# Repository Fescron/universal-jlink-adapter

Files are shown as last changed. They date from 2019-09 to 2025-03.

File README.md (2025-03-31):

# Universal J-Link Adapter







<br/>

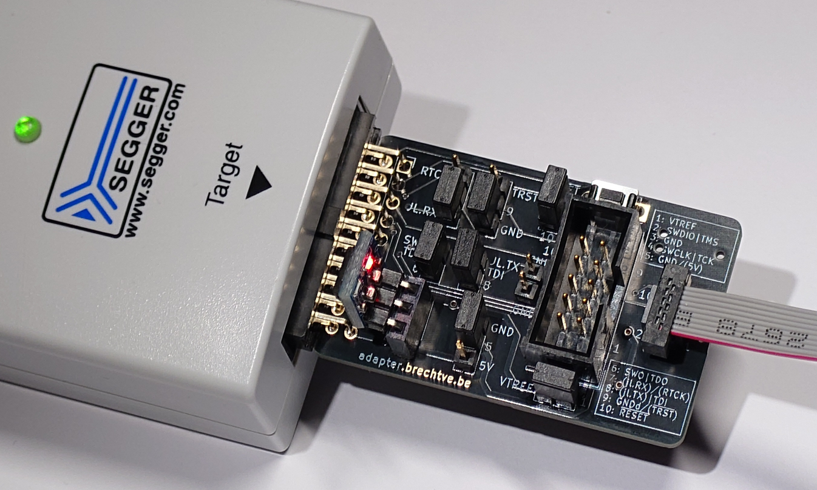
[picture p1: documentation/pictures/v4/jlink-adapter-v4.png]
Universal J-Link adapter on J-Link EDU debugger


<br/>

| Quick access links                                                                                                                                                                        |
| ----------------------------------------------------------------------------------------------------------------------------------------------------------------------------------------- |
| [Adapter v4.0 **schematic** (PDF)](hardware/jlink-tagConnect-adapter-v4/jlink-tagConnect-adapter-v4.pdf) // [Adapter v4.0 **gerber-files**](hardware/jlink-tagConnect-adapter-v4/Gerber/) |
| [Basic **J-Link Commander** usage and using **Segger Real-Time Transfer (RTT)** (instead of UART) for real-time debugging](JLinkExe-SeggerRTT-debugging-TipsTricks.md)                    |

<br/>

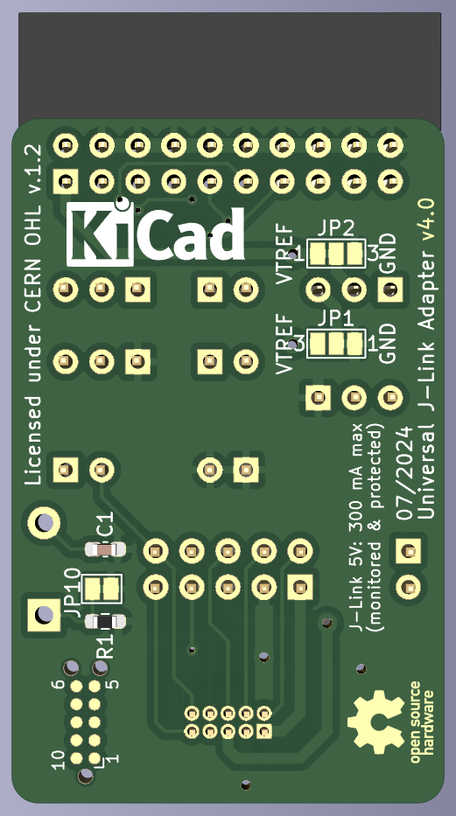
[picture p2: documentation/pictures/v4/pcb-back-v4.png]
Back of the adapter board


This multifunctional adapter board, primarily designed for use with a [J-Link debugger](https://www.segger.com/products/debug-probes/j-link/) (but others which follow the standard 20-pin JTAG/SWD pinout also work), allows the user to have the standard [9 pin Cortex-M SWD/JTAG pinout](https://www.segger.com/products/debug-probes/j-link/accessories/adapters/9-pin-cortex-m-adapter/) on both a 0.1" (2.54mm) and 0.05" (1.27mm) male pinheader. With additional jumpers it is possible to have **extra functionality** like **UART debugging though the J-Link's VCOM** on pins which normally aren't used in some modes, if the probe's hardware supports this. Good **labeling of all pin numbers and their corresponding functionality** also help to speed-up the embedded-development process. Additional information regarding the pinout of *default* SWD-headers as well as the voltage output of the J-Link debugger are also printed on the board, along with the pin-numbers of the [10 pin Tag-Connect header](http://www.tag-connect.com/TC2050-IDC).

Furthermore, the adapter PCB can **power the target board** through the `VTREF` connection. For this to work a **DC-DC converter or LDO regulator** can be plugged into the female 3-pin socket on the adapter board to allow the J-Link's 5V-Supply to be converted to, for example 3.3V. Various 3-pin voltage conversion boards are supported due to solder-jumpers available on the back of the adapter, allowing for the `VOUT`and `GND`pins to be swapped around. The 5V voltage can also be supplied *as-is* on a header pin by changing a jumper position.

Finally a physical reset button (with optional 100 Ω series-resistor and 100 nF filter capacitor) can be used to manually pull the reset line low, even if no debugger is connected. This eliminates the need to add a reset button to the target board and thus saves valuable board space.

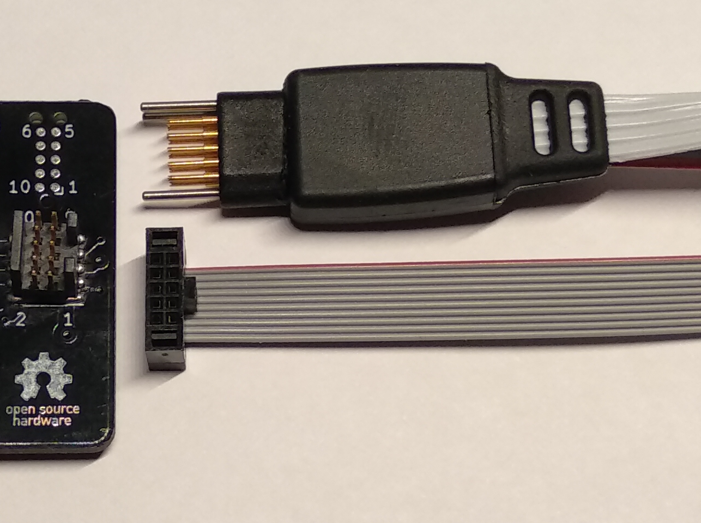
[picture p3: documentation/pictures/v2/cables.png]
Headers and corresponding cables


The **0.05" (1.27mm) header** is recommended for when the target board is mostly connected to the debugger and the board in question also has a header of this size. The **0.1" (2.54mm) IDC header** is recommended for use with either regular jumper-wires or a [10 pin Tag-Connect adapter cable](http://www.tag-connect.com/TC2050-IDC). The latter allows target boards to be programmed without having to need a dedicated programming connector mounted, and thus saves on cost.

The figure on the left depicts the `TagConnect 2050` (*no-legs*) cable on the top-right, next to its corresponding footprint. Below this is a 0.05" header with its corresponding cable.

<br/>
<br/>

## 0 - Table of Contents

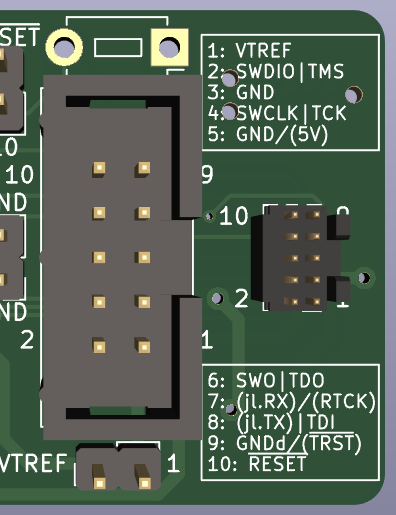
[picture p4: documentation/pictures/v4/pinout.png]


- [Universal J-Link Adapter](#universal-j-link-adapter)
  - [0 - Table of Contents](#0---table-of-contents)
  - [1 - Adapter functionality](#1---adapter-functionality)
    - [1.1 - Supply power to the target board (5V and/or other voltages)](#11---supply-power-to-the-target-board-5v-andor-other-voltages)
    - [1.2 - Additional functionality on "unused" pins using jumpers (and corresponding tips and tricks)](#12---additional-functionality-on-unused-pins-using-jumpers-and-corresponding-tips-and-tricks)
  - [2 - Serial flashing](#2---serial-flashing)
  - [3 - Layout guidelines for target boards](#3---layout-guidelines-for-target-boards)
  - [4 - BOM](#4---bom)
  - [5 - KiCad debug header symbols](#5---kicad-debug-header-symbols)

<br/>

## 1 - Adapter functionality

Aside from the ability to easily make connections to target boards using the well-labeled pinout and corresponding functionality of both output-headers, the following paragraphs give more information regarding additional features this adapter can provide.

<br/>

:pencil: **Note:** The pinout silkscreen has the following syntax:

- `... | ...`: The same (J-Link debugger) pin has different SWD or JTAG functionality
- `... / ...`: A jumper can be used to route one or the other signal to this pin
- `(...)`: This pin-signal deviates from the default SWD or JTAG pinout

<br/>

### 1.1 - Supply power to the target board (5V and/or other voltages)

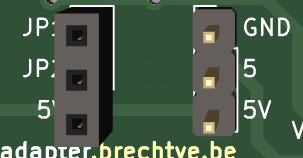
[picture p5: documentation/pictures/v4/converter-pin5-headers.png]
Converter and pin-5 headers


As previously stated, a **DC-DC converter or LDO regulator** can be plugged into the 3-pin female header on this adapter with the labels `JP1 JP2 5V`. This would allow the adapter board to supply power through the `VTREF`-line (`PIN 1`) to the target board with the correct voltage, derived from the **5V supply of the J-Link debugger**. The 5V voltage can **also be made available *as-is* on** `PIN 5` of the output headers, by placing a jumper in the correct position of the header labeled `GND 5 5V`. With the same jumper `GND` can also be made available on `PIN 5`. Both the voltage-converter socket and `PIN 5`-jumper are depicted on the figure on the left.

If the user wishes to **not power the target board using** `VTREF`, for example in case of it already receiving power from a battery or external supply, the **voltage converter should simply not be plugged in**. The J-Link debugger will still receive the correct I/O voltage as a logic-level reference if the MCU's supply voltage is present on `VTREF` (`PIN 1`).

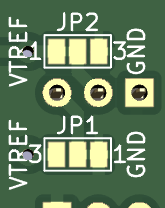
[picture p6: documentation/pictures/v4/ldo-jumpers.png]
Voltage-converter pinout jumpers


If the **pinout of the 3-pin voltage converter doesn't match** `VIN - VOUT - GND`, the last two pins can be changed around by swapping the solder joints on `JP1` and `JP2` on the bottom of the PCB. This is also also depicted on the figure on the left. If the present copper traces are cut on both jumpers and new solder connections are made on the opposite side, the pinout `VIN - GND - VOUT` will be selected.

<br/>

The **5V output needs to be enabled on the J-Link** using the [J-Link Commander](https://kb.segger.com/J-Link_Commander) software (`JLink.exe/JLinkExe`). The following command needs to be executed for the 5V supply to be always enabled:

```shell
Power On perm
```

<br/>

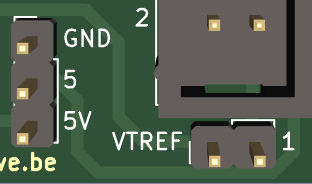
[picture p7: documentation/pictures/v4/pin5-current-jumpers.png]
Current-measurement jumpers


If the target board is powered via a voltage-converter on the adapter PCB, a jumper labeled `VTREF 1` below the 0.1" header allows for a **current meter** to be inserted between the converter and target board. This way its power usage can be monitored, for example in case the J-Link probe doesn't have this functionality build-in. If 5V is supplied to the target board through `PIN 5`, a jumper in this location can also be substituted for a current meter. Both headers are depicted on the figure on the right.

<br/>

### 1.2 - Additional functionality on "unused" pins using jumpers (and corresponding tips and tricks)

In addition to the *default* SWD or JTAG pinouts it is also possible to add extra functionality to normally *unused* pins of the 02x05 headers:

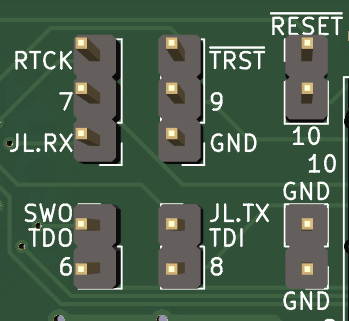
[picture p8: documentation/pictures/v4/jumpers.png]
Jumpers which allow for additional functions on pins


- :pushpin: **PIN 5** is normally connected to `GND`.
  - On the [Segger 10 pin Needle Adapter](https://www.segger.com/products/debug-probes/j-link/accessories/adapters/10-pin-needle-adapter/) this pin outputs the J-Link's `5V-Supply`. A jumper on the adapter board can be used to select this, which was already mentioned in the previous section.
  - :bulb: **TIP:** See the [following section](#2---serial-flashing) to use this pin for **serial programming**.
- :pushpin: **PIN 6** is normally used for the `SWO` or `TDO` connection. A jumper labeled `SWO TDO 6`, which can be seen on the figure on the right, can however be used to disconnect the debugger from the target board.
  - :bulb: **TIP:** Disconnecting the pin from the debugger can enable the MCU's output pin to be used as a GPIO debug signal. It can for example be set high if some code is running, and low when this is not the case. Simply remove the jumper and add a jumper-wire on the pin labeled `6`.
- :pushpin: **PIN 7** is on the [standard 9-pin Cortex-M SWD/JTAG pinout](https://www.segger.com/products/debug-probes/j-link/accessories/adapters/9-pin-cortex-m-adapter/) *not populated* since this is the **key**.
  - **SWD mode:** A jumper labeled `RTCK 7 JL.RX` can be used to connect this pin to the J-Link's **VCOM** `RX` pin. This way UART debugging can be used in conjunction with SWD.
    - :bulb: **TIP:** The jumper can also be removed, and a separate UART `TXD` signal from a target board can be connected to the J-Link's `RX` input by connecting a jumper-wire to the `JL.RX` pin.
    - :pencil: **NOTE:** It is possible VCOM needs to be enabled on the probe. This can be done using [J-Link Commander](https://kb.segger.com/J-Link_Commander) (`JLinkExe/JLink.exe`) by executing the following command (VCOM will start working after the next power-cycle):
      ```shell
      VCOM enable
      ```
  - **JTAG mode:** The same jumper can also be used to connect this pin to `RTCK` if necessary.
- :pushpin: **PIN 8**
  - **SWD mode:** Normally this pin is *not connected*, but a jumper labeled `JL.TX TDI 8` allows it to be connected to the J-Link's **VCOM** `TX` pin.
    - :bulb: **TIP:** The jumper can also be removed, and a separate UART `RXD` signal from a target board can be connected to the J-Link's `TX` output by connecting a jumper-wire to the `JL.TX` pin.
  - **JTAG mode:** On Segger's [9 pin](https://www.segger.com/products/debug-probes/j-link/accessories/adapters/9-pin-cortex-m-adapter/) and [19 pin](https://www.segger.com/products/debug-probes/j-link/accessories/adapters/19-pin-cortex-m-adapter/) Cortex-M adapters `PIN 9` is connected to `TDI`.
    - :bulb: **TIP:** The `TDI` signal of a J-Link debugger can be set *low* or *high* using **J-Link Commander** by executing `TDI0` and `TDI1` respectively, even if there is no target connection active. This signal can thus be used as a GP(I)O line to, for example, an MCU input pin.
  - :pencil: **NOTE:** `JL.TX` and `TDI` are for both modes located on the same physical J-Link pin. This means the jumper should normally not need to be disconnected when using the adapter in one or the other mode.
- :pushpin: **PIN 9**
  - **SWD mode:** Normally this pin is *not connected*. Sometimes a target board however uses this pin as `GNDdetect`, so it can (as the name implies) detect the presence of a debugger. With a jumper labeled `nTRST 9 GND` this pin can be connected to `GND` to enable this functionality.
    - :bulb: **TIP:** When `PIN 9` is connected to a microcontroller pin which can act as an output, the adapter can be used to *break-out* this pin to another instrument for, for example, code-timing analysis. Simply remove the jumper and add a jumper-wire on the pin labeled `9`.
  - **JTAG mode:** On Segger's [9 pin](https://www.segger.com/products/debug-probes/j-link/accessories/adapters/9-pin-cortex-m-adapter/) and [19 pin](https://www.segger.com/products/debug-probes/j-link/accessories/adapters/19-pin-cortex-m-adapter/) Cortex-M adapters this pin can be connected to `nTRST` using a solder jumper. On this adapter board this can be done using a regular jumper.
    - :bulb: **TIP:** The `nTRST` signal of a J-Link debugger can be set *low* or *high* using **J-Link Commander** by executing `TRST0` and `TRST1` respectively, even if there is no target connection active. This signal can thus be used as a GP(I)O line to, for example, an MCU input pin.
- :pushpin: **PIN 10** is used to reset the target board. A jumper is present to disconnect this line if necessary.
  - :bulb: **TIP:** The `nRESET` signal of a J-Link debugger can be set *low* or *high* using **J-Link Commander** by executing `R0` and `R1` respectively, even if there is no target connection active.<br/>Reset button circuit
  - An `nRESET` button is also present on the adapter board to manually pull the reset line low. An optional (100 Ω) series-resistor `R1` and (100 nF) filter capacitor C1 can be mounted on the bottom of the board, both in the 0603 package. They are depicted on the figure on the right. To *activate* the functionality of `R1` jumper `JP10` has to be cut.

<br/>

:bulb: **TIP:** `ShowHWStatus` or `ST` can be executed in **J-Link Commander** to show the current `VTREF` voltage as well as the signal-level of the `SWCLK|TCK`, `TDI`, `SWO|TDO`, `SWDIO|TMS`, `nRESET` (`TRES`) and `nTRST` pins, even if there is no target connection active.

Additionally a two-pin `GND` header, next to the `JL.TX TDI 8` jumper, also facilitates some additional ground-wire connections for general debug connections.

<br/>

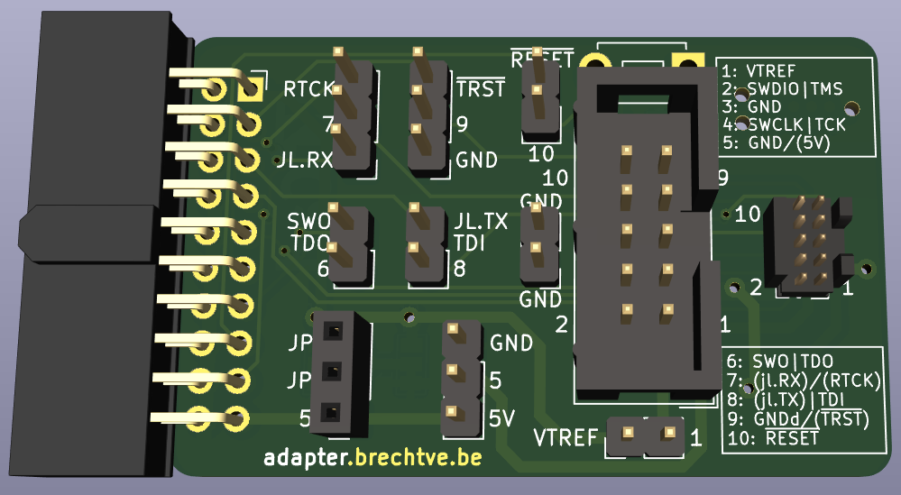
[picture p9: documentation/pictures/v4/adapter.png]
Front of the adapter board


<br/>

## 2 - Serial flashing

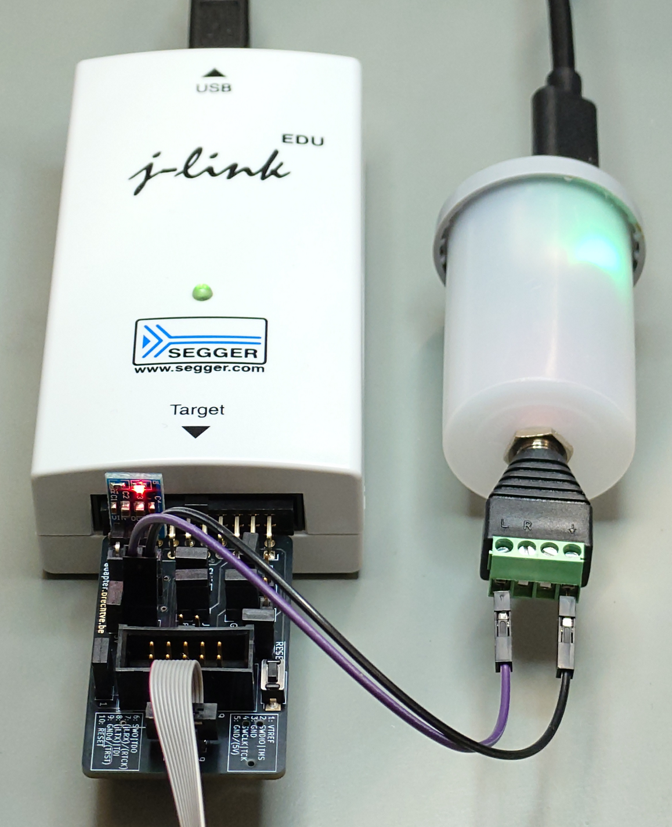
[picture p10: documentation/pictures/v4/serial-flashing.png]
Universal J-Link Adapter Board and Macropedal for Serial Flashing


Due to the availability of the jumpers on the adapter PCB certain pins can also be used to detect if a target board is plugged in. A board such as the [Macropedal](https://github.com/Fescron/macropedal) can for example be used to check if `pin 5` is, via a target board, connected to ground. If this is the case, the *Macropedal* can enter a command in a terminal to flash firmware to a board. This way one after the other board can be programmed in a **series production** scenario. The target board can even be powered by the adapter itself for a complete *stand-alone* setup. The figure on the right depicts such an arrangement. Refer to [Segger J-Link debugging tips & tricks - 2 - Scripting](JLinkExe-SeggerRTT-debugging-TipsTricks.md#2---scripting) for more information.

<br/>

## 3 - Layout guidelines for target boards

It is advised to add the following passives to the *target board* for protection and stability. This is also mentioned on the [adapter schematic](hardware/jlink-tagConnect-adapter-v4/jlink-tagConnect-adapter-v4.pdf).

- 10 kΩ pullup on `SWDIO|TMS`, `TDO` and `TDI` (and the target board's `RXD` line)
- 10 kΩ pulldown on `SWCLK|TCK`
- 33 to 100 Ω in-line current-limiting resistors on `TXD` and `RXD` lines
  - This can be important for when UART is available on a (0.1") external header, and is less important if this is made available on the SWD-header. 100 pF capacitors (*after* the series resistors) can also help with some filtering and ESD mitigation.

<br/>

## 4 - BOM

| Component | Footprint | Manufacturer `Partnumber` | Ordering |
| --- | --- | --- | --- |
| J1 | 02x10 0.1" (2.54mm) Right Angle Keyed Female IDC Socket  | Sullins `SFH11-PBPC-D10-RA-BK` | [digikey.be](https://www.digikey.be/product-detail/en/sullins-connector-solutions/SFH11-PBPC-D10-RA-BK/S9205-ND/1990098) |
| J2 | 02x05 0.1" Male Key-Shrouded IDC Header | Samtec `TST-105-01-L-D` | [digikey.be](https://www.digikey.be/en/products/detail/samtec-inc/TST-105-01-L-D/2685818) |
| J3 | 02x05 0.05" (1.27mm) Male Key-Shrouded Header | Samtec `FTSH-105-01-L-D-K` | [digikey.be](https://www.digikey.be/en/products/detail/samtec-inc/FTSH-105-01-L-D-K/2649979) |
| J4 | 01x03 0.1" Female IDC Socket | Samtec `SSW-103-01-G-S` | [digikey.be](https://www.digikey.be/en/products/detail/samtec-inc/SSW-103-01-G-S/1112104) |
| J5, JP4, JP5, JP8, JP9 | 01x02 0.1" Male IDC Header | Samtec `TSW-102-07-L-S` | [digikey.be](https://www.digikey.be/en/products/detail/samtec-inc/TSW-102-07-L-S/1101425) |
| JP3, JP6, JP7 | 01x03 0.1" Male IDC Header | Samtec `TSW-103-07-L-S` | [digikey.be](https://www.digikey.be/en/products/detail/samtec-inc/TSW-103-07-L-S/1101424) |
| SW1 | 6.5mm Pitch Through-hole Switch | C&K `PTS636SL43 LFS` | [digikey.be](https://www.digikey.be/en/products/detail/c-k/PTS636SL43-LFS/10071714) |
| R1 | 100 Ω 0603 1% (1 kΩ should also work) | Yageo `RC0603FR-07100RL` | [digikey.be](https://www.digikey.be/en/products/detail/yageo/RC0603FR-07100RL/726888) |
| C1 | 100 nF 0603 10% 50V X7R | Yageo `CC0603KRX7R9BB104` | [digikey.be](https://www.digikey.be/en/products/detail/yageo/CC0603KRX7R9BB104/2103082) |
| | 2.54mm Pitch Jumpers | Samtec `SNT-100-BK-G` | [digikey.be](https://www.digikey.be/en/products/detail/samtec-inc/SNT-100-BK-G/1756763) |
| | 02x05 0.05" IDC Cable, 6 inch (15 cm) Long | Samtec `FFSD-05-D-06.00-01-N`  | [digikey.be](https://www.digikey.be/en/products/detail/samtec-inc/FFSD-05-D-06-00-01-N/1106577) |
| | TagConnect 10 pin IDC to Needles Without Legs (`...-NL`) | TagConnect `TC-2050-IDC-NL` | [digikey.be](https://www.digikey.be/product-detail/nl/tag-connect-llc/TC2050-IDC-NL/TC2050-IDC-NL-ND/2605367) |
| | TagConnect 10 pin IDC to Needles | TagConnect `TC-2050-IDC` | [digikey.be](https://www.digikey.be/en/products/detail/tag-connect-llc/TC2050-IDC/2605366) |

<br/>

## 5 - KiCad debug header symbols

On the repository [brechtve-kicad-things](https://github.com/Fescron/brechtve-kicad-things) symbols are available where the additional functionality, selectable using the jumpers, is depicted for both SWD and JTAG modes. The *regular* pinouts are put into brackets. The symbols can be found in the library [`BrechtVE_DebugHeader.lib`](https://github.com/Fescron/brechtve-kicad-things/blob/master/Libraries/BrechtVE_DebugHeader.lib).

The symbols to be linked to a **0.05" (1.27mm) header** on the target board are the following:

<div style="text-align: center">
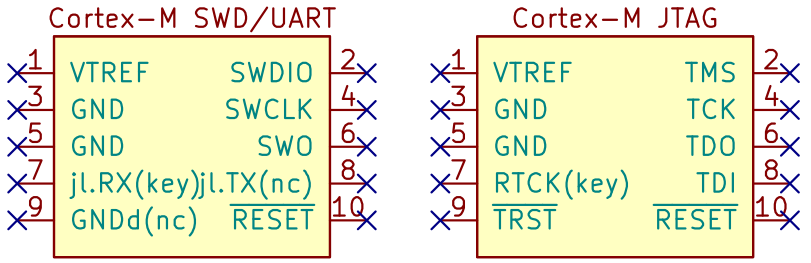
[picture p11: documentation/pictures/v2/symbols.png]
SWD/JTAG symbols for 0.05inch header

</div>

<br/>

Symbols are also supplied to be linked to a **TagConnect 2050 footprint**. The pin numbers and corresponding functions are mostly the same as for the previously mentioned SWD/JTAG connectors, but the direction in which the pins are laid out on the PCB is different. This is reflected in other symbols:

<div style="text-align: center">
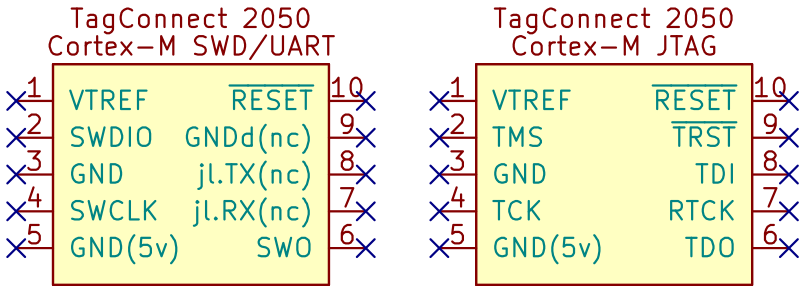
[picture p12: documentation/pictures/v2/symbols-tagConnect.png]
SWD/JTAG symbols for TagConnect 2050 footprint

</div>

<br/>

For reference these symbols, along with additional information regarding jumpers and layout guidelines, can be found on the [adapter schematic](hardware/jlink-tagConnect-adapter-v4/jlink-tagConnect-adapter-v4.pdf). A lot more information regarding [KiCad](https://www.kicad.org/) itself is also available on the repository [brechtve-kicad-things](https://github.com/Fescron/brechtve-kicad-things).

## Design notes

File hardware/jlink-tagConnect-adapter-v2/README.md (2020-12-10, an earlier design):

# Universal J-Link Adapter







<br/>

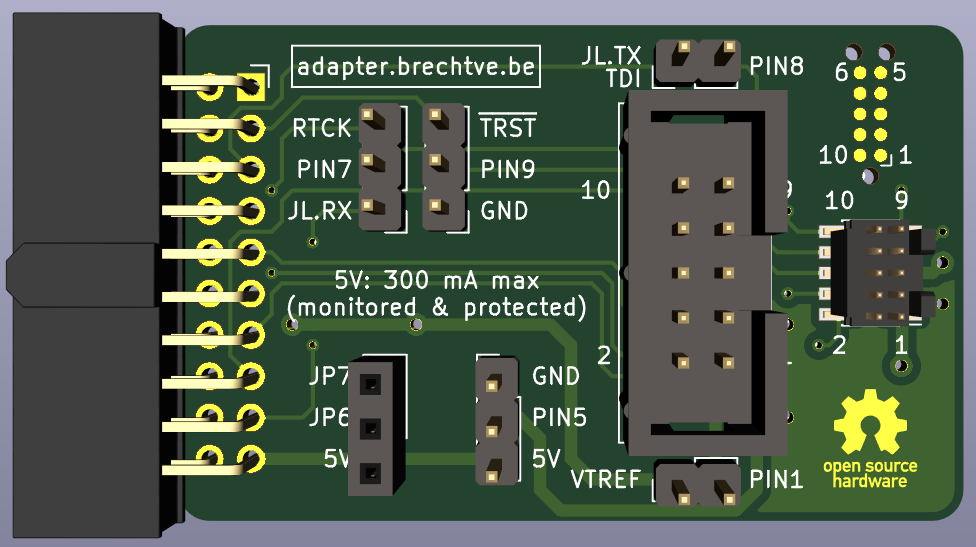
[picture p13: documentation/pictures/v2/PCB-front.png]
Adapter PCB
 Adapter with J-Link

<br/>

- [Quick link to the schematic](hardware/jlink-tagConnect-adapter-v2/jlink-tagConnect-adapter-v2.pdf)

<br/>

This multifunctional adapter board, primarily designed for use with a [J-Link debugger](https://www.segger.com/products/debug-probes/j-link/models/j-link-base/) (or others which follow its standard 20-pin JTAG/SWD pinout), allows the user to have the standard [9 pin Cortex-M SWD/JTAG pinout](https://www.segger.com/products/debug-probes/j-link/accessories/adapters/9-pin-cortex-m-adapter/) on both a 0.1" (2.54mm) and 0.05" (1.27mm) header. With additional jumpers, it's possible to have **extra options (for example UART debugging though the J-Link's VCOM) on pins that normally aren't used in some modes**. The adapter can also **power the target board** through `VTREF`. A DC-DC converter can be plugged in on the adapter to allow the J-Link's `5V-Supply` to be converted to, for example 3.3V.

The **0.05" header** is recommended for development when the target board is mostly connected to the debugger. The **0.1" IDC header** is recommended for use with a [10 pin Tag-Connect adapter cable](http://www.tag-connect.com/TC2050-IDC), so target boards can quickly be reprogrammed *on-location*.

Cables

On the picture next to this text on top you can see this TagConnect 2050 cable next to its corresponding PCB footprint. Below you can see the 0.05" header with its corresponding cable.

<br/>

A lot of useful information is also printed on the *silkscreen* of the PCB. Noteworthy is the **pinout numbering** of the 0.1" and 0.05" headers (wich are connected to SWD/JTAG pins) and also the numbering of the 10-pin Tag-Connect header on the front. The **functions for every pin** are also printed on the back of the PCB.

<br/>

## 1 - Functions

### 1.1 - Supply power to a target board

A **DC-DC converter** can be plugged in on the header with the labels `5V JP6 JP7` to supply the target board with the correct voltage, derived from the 5V supply of the J-Link programmer. If the pinout of the converter doesn't match `VIN - VOUT - GND`, the last two pins can be changed around by swapping the solder joints on `JP6` and `JP7` on the bottom of the PCB. Then the pinout `VIN - GND - VOUT` will be selected.

This 5V output needs to be enabled on the J-Link using the `J-Link Commander` (`JLinkExe`) software. The following command needs to be called for the 5V supply to be always enabled:

```shell
power on perm
```

If the user wishes to **not power the target board using `VTREF`** (for example in the case that the target board is already getting its own power from a battery), the **DC-DC converter should simply not be plugged in**.

<br/>

**PIN 1** (`VTREF`) normally supplies the J-Link adapter with a voltage to allow it to generate the correct logic levels. With this adapter board the target board can be powered through `VTREF` using the previously mentioned DC-DC converter. A jumper is supplied below the 0.1" header to allow a **current meter** to be plugged in-line between the DC-DC converter and the target board so the power usage can be monitored.

<br/>

### 1.2 - Additional functionality on unused pins using jumpers

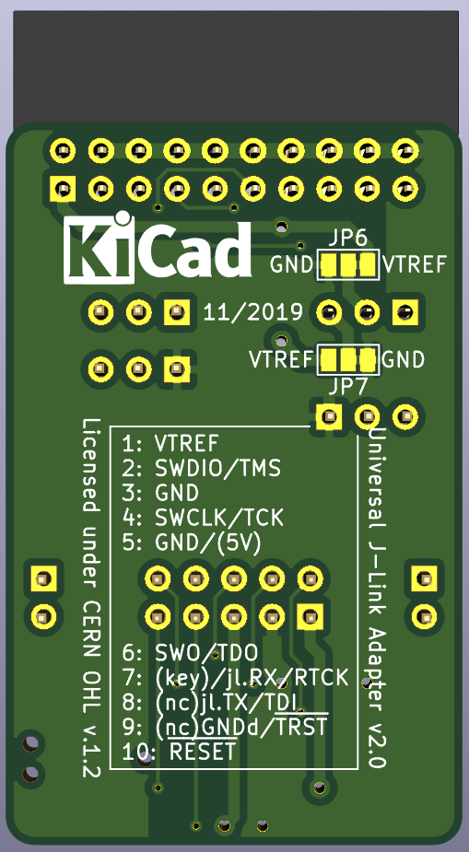
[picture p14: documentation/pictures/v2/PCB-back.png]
Back


- **PIN 5** is normally connected to GND.
  - On the [J-Link 10 pin Needle Adapter](https://www.segger.com/products/debug-probes/j-link/accessories/adapters/10-pin-needle-adapter/) this pin outputs the J-Link's `5V-Supply`. A jumper can be used to select this.
- **PIN 7** is on the [standard 9-pin Cortex-M SWD/JTAG pinout](https://www.segger.com/products/debug-probes/j-link/accessories/adapters/9-pin-cortex-m-adapter/) *not populated* since this is the **key**.
  - **SWD mode:** A jumper can be used to connect this pin to the J-Link's VCOM `RX` pin, so UART debugging functionality can be used in conjunction with SWD.
  - **JTAG mode:** The same jumper can also be used to connect this pin to `RTCK` if necessary.
- **PIN 8**
  - **SWD mode:** Normally this pin is *not connected*, but a jumper allows it to be connected to the J-Link's VCOM `TX` pin.
  - **JTAG mode:** On J-Link's [9 pin](https://www.segger.com/products/debug-probes/j-link/accessories/adapters/9-pin-cortex-m-adapter/) and [19 pin](https://www.segger.com/products/debug-probes/j-link/accessories/adapters/19-pin-cortex-m-adapter/) Cortex-M adapters this pin is connected to `TDI`.
  - *NOTE:* `TX` and `TDI` are in both modes on the same pin. This means that normally this pin shouldn't be disconnected but a jumper allows this just in case.
- **PIN 9**
  - **SWD mode:** Normally this pin is *not connected*, but sometimes a target board uses this pin as `GNDdetect` so it can detect the presence of a debugger. With a jumper this pin can be connected to GND to enable this functionality.
  - **JTAG mode:** On J-Link's [9 pin](https://www.segger.com/products/debug-probes/j-link/accessories/adapters/9-pin-cortex-m-adapter/) and [19 pin](https://www.segger.com/products/debug-probes/j-link/accessories/adapters/19-pin-cortex-m-adapter/) Cortex-M adapters this pin can be connected to `nTRST` using a solder jumper. On this adapter board this can be done using a regular jumper.

<br/>

## 2 - KiCad debug header symbols

On the repository [brechtve-kicad-things](https://github.com/Fescron/brechtve-kicad-things) (kicad.brechtve.be) you can find some symbols (and a lot of additional information regarding KiCad) where these additional functions, selectable using the jumpers, are depicted for both SWD and JTAG modes. They can be found in the library `BrechtVE_DebugHeader.lib`. The symbols can be linked to a 0.05" header on the target board and are:

SWD/JTAG symbols

<br/>
<br/>

Symbols are also supplied that can be linked to a TagConnect 2050 footprint. The pin numbers and corresponding functions are mostly the same as the previously mentioned SWD/JTAG connectors, but the direction in wich the pins are layed out on the PCB are different. This is reflected in other symbols:

SWD/JTAG symbols

<br/>
<br/>

For reference, these symbols (and additional information regarding for example jumpers and layout guidelines) can be found on the [adapter schematic](hardware/jlink-tagConnect-adapter-v2/jlink-tagConnect-adapter-v2.pdf).

<br/>

## 3 - Layout guidelines for target board

It's advised to add the following passives on the *target board* for protection and stability:
- 100 kΩ pullup on `SWDIO`.
- 10 kΩ pullup on `RXD`.
- 100 Ω inline current limiting resistors on `TXD` and`RXD` lines (mostly used for additional external headers)

<br/>

## 4 - BOM

- 0.1" = 2.54mm
- 0.05" = 1.27mm

| Component | Footprint | Type | Ordering |
| --- | --- | --- | --- |
| J1 | 02x10 0.1" Right Angle Female IDC socket | Sullins `SFH11-PBPC-D10-RA-BK` | [digiKey.be](https://www.digikey.be/product-detail/en/sullins-connector-solutions/SFH11-PBPC-D10-RA-BK/S9205-ND/1990098) |
| | 02x10 0.1" Right Angle Female socket | Samtec `SSW-110-02-L-D-RA` | [mouser.be](https://www.mouser.be/ProductDetail/Samtec/SSW-110-02-L-D-RA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) |
| J2 | 02x05 0.1" Male IDC header | Samtec `TST-105-01-L-D` | [mouser.be](https://www.mouser.be/ProductDetail/Samtec/TST-105-01-L-D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) |
| J3 | 02x05 0.05" Male Key-Shrouded SMD header | Samtec `FTSH-105-01-L-DV-K` | [mouser.be](https://www.mouser.be/ProductDetail/Samtec/FTSH-105-01-L-DV-K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) |
| | Through hole variant to put on some target boards | Samtec `FTSH-105-01-L-D-K` | [mouser.be](https://www.mouser.be/ProductDetail/Samtec/FTSH-105-01-L-D-K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) |
| J4 | 01x03 0.1" Female socket | Samtec `SSW-103-01-L-S` | [mouser.be](https://www.mouser.be/ProductDetail/Samtec/SSW-103-01-L-S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) |
| JP1, JP2, JP3 | 01x03 Male pinheader (pins: 5,84 mm long) | Samtec `TSW-103-07-L-S` | [mouser.be](https://www.mouser.be/ProductDetail/Samtec/TSW-103-07-L-S?qs=sGAEpiMZZMvlX3nhDDO4AF6ANhyOCHSy6PrTyFT9uaw%3D) |  |
| JP4, JP5 | 01x02 Male pinheader (pins: 5,84 mm long) | Samtec `TSW-102-07-L-S` | [mouser.be](https://www.mouser.be/ProductDetail/Samtec/TSW-102-07-L-S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) |
| | Shunt/jumper | Samtec `SNT-100-BK-G` | [mouser.be](https://www.mouser.be/ProductDetail/Samtec/SNT-100-BK-G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) |
| | TagConnect 10 pin IDC to needles without legs | `TC-2050-IDC-NL` | [digikey.be](https://www.digikey.be/product-detail/nl/tag-connect-llc/TC2050-IDC-NL/TC2050-IDC-NL-ND/2605367) |
| | 2x05 0.05" IDC cable, 6 inch (15 cm) long, strain relief | Samtec `FFSD-05-D-06.00-01-N-SR` | [mouser.be](https://www.mouser.be/ProductDetail/Samtec/FFSD-05-D-0600-01-N-SR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) |

<br/>

**Samtec**

- `L`: 10 µ" (0.25 µm) Gold on post/contact, Matte Tin on tail
- `F`: Gold flash on post/contact, Matte Tin on tail
- [SSW configuration utility](https://www.samtec.com/products/ssw)
- [TST configuration utility](https://www.samtec.com/products/tst)
- [FTSH configuration utility](https://www.samtec.com/products/ftsh)
- [TSW configuration utility](https://www.samtec.com/products/tsw)
- [FFSD configuration utility](https://www.samtec.com/products/ffsd)
- 0.05" 9 pin (polarized) header: `FTSH-105-01-L-DV-007-K`

<br/>

## 5 - Order PCB directly from OSHPARK

**TODO**

<br/>

## 6 - Future improvements

- Change the 0.05" programming header to use the (smd)/through hole variant of a shrouded IDC header
   - `ESHF-105-01-L-D-TH` ([mouser.be](https://www.mouser.be/ProductDetail/Samtec/ESHF-105-01-L-D-TH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))
   - [ESHF configuration utility](https://www.samtec.com/products/eshf)
- When `GNDdetect` is connected to a MCU GPIO pin, the jumper can be removed and the signal on pin 9 can be read with another device to allow for extra debug information.
- `SWO` disconnect jumper? (extra GPIO for debugging)

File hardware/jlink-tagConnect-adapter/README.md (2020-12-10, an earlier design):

# jlink-tagConnect-adapter v1.0

<br/>

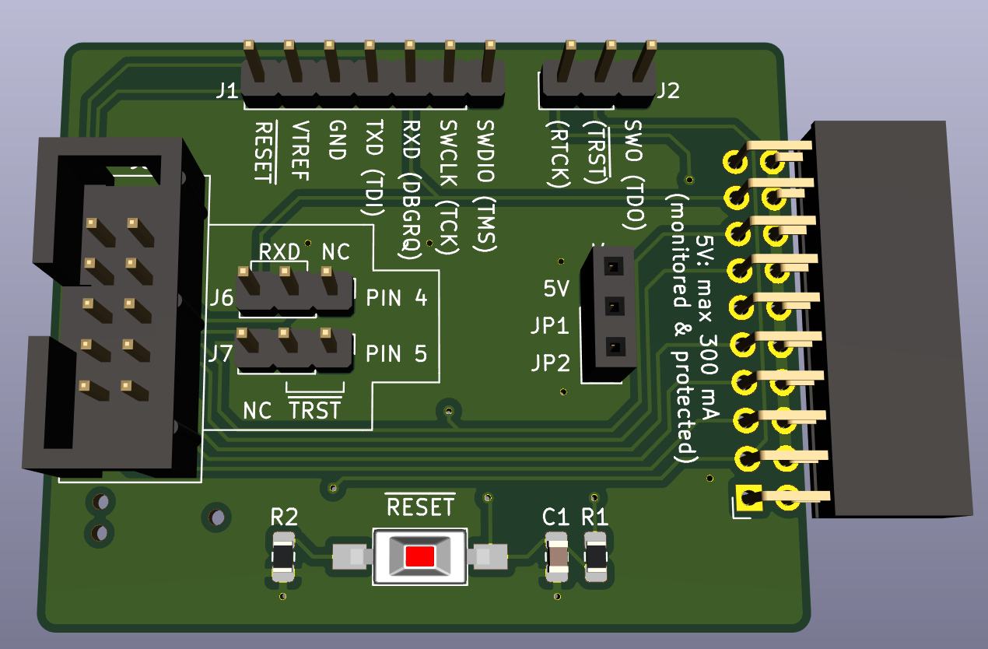
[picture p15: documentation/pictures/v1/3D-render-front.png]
Front
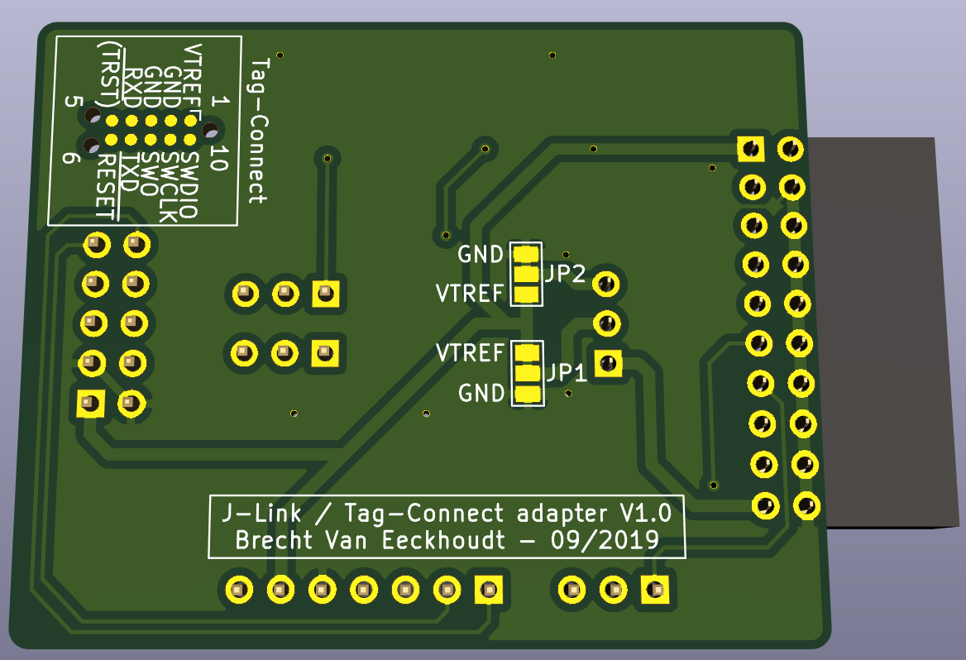
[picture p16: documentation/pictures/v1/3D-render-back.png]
Back
 

**This is an old version of the board and was never really used since it didn't follow the J-Link Needle adapter pinout. It's kept here for documentation purposes.**

- [Schematic](hardware/jlink-tagConnect-adapter/jlink-tagConnect-adapter.pdf)

<br/>

## 1 - Usage

One can plug this *4cm x 5cm* adapter board in a [J-Link debugger](https://www.segger.com/products/debug-probes/j-link/models/j-link-base/) along with a [10 pin Tag-Connect adapter cable](http://www.tag-connect.com/TC2050-IDC) on the IDC connector. The cable will then have the approximate pinout (`RXD` instead of pin 7 `NC`) of the [standard 9-pin Cortex-M SWD/JTAG pinout](https://www.segger.com/products/debug-probes/j-link/accessories/adapters/9-pin-cortex-m-adapter/) from J-Link. The pinout of the Tag-Connect cable can be seen on the picure below (and for reference also on the bottom of the adapter board, but its pins aren't connected).

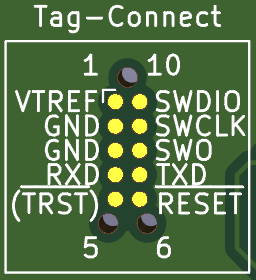
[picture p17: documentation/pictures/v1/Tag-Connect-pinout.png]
Tag-Connect pinout


- **Pinheaders** `J1` and `J2` can be used to break out the SWD/JTAG pins to a 2.54mm standard header.
- **Pushbutton** `SW1` can be used to mannually **reset** the target board.
- A **DC-DC converter** can be plugged in on header `J4` to supply the target board with the correct voltage using the 5V supply of the J-Link programmer.
  - If the pinout of the converter doesn't match `VIN - VOUT - GND`, the last two pins can be changed around by swapping the solder joints on `JP1` and `JP2` on the bottom of the adapter. Then the pinout `VIN - GND - VOUT` will be selected.
- **Jumpers** `J6` and `J7` can also be used to swap some pinouts around. `J6` connects `pin 4` on the Tag-Connect cable to `RXD` or *doesn't connect it*. `J7` connects `pin 5` on the Tag-Connect cable to *nothing* or to `nTRST` (JTAG).

<br/>

## 2 - BOM

| Component | Value |
| --- | --- |
| J1 | 01x07 Male pinheader |
| J2 | 01x03 Male pinheader |
| J3 | 02x10 Female IDC connector ([DigiKey link](https://www.digikey.be/product-detail/en/sullins-connector-solutions/SFH11-PBPC-D10-RA-BK/S9205-ND/1990098)) |
| J4 | 01x03 Female pinsocket |
| J5 | 02x05 Male IDC header |
| J6 | 01x03 Male pinheader (+ jumper) |
| J7 | 01x03 Male pinheader (+ jumper) |
| R1 | 1 kΩ 0805 Resistor |
| R2 | 100 Ω 0805 Resistor |
| C1 | 100 nF 0805 Capacitor |
| SW1 | 2 pin SPST tact switch |

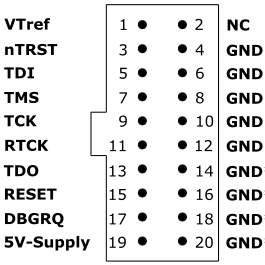
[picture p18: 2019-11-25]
documentation/pinouts/jlink-jtag-pinout.png

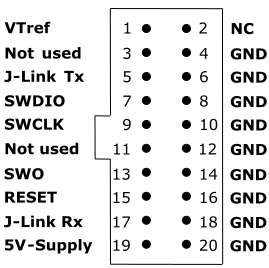
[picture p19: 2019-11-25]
documentation/pinouts/jlink-swd+vcom-pinout.png

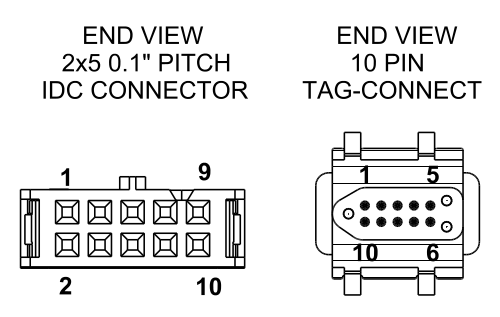
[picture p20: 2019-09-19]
documentation/pinouts/pinout-tag-connect.png

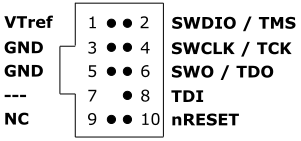
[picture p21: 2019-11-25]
documentation/pinouts/jlink-jtag-swd-9pin-pinout.png

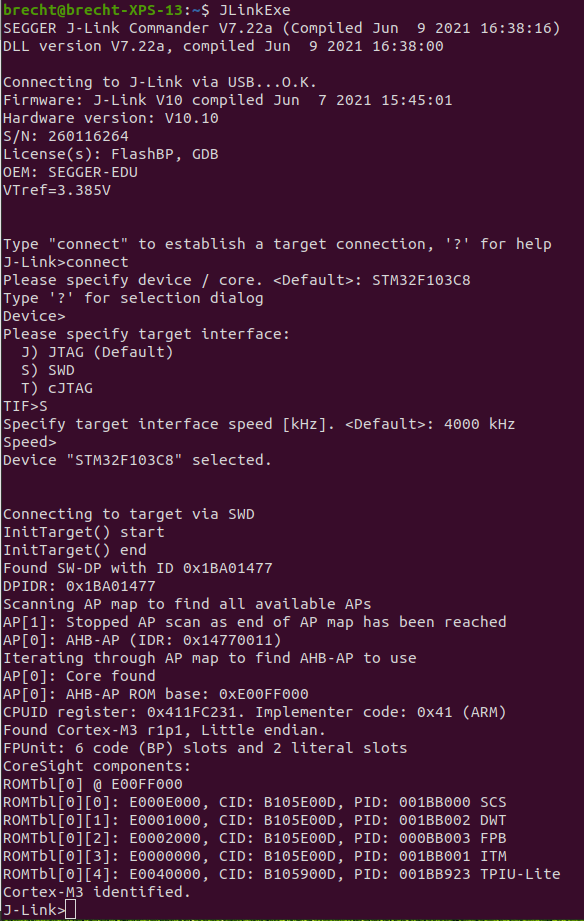
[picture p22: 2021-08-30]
documentation/pictures/JLink/JLinkExe.png

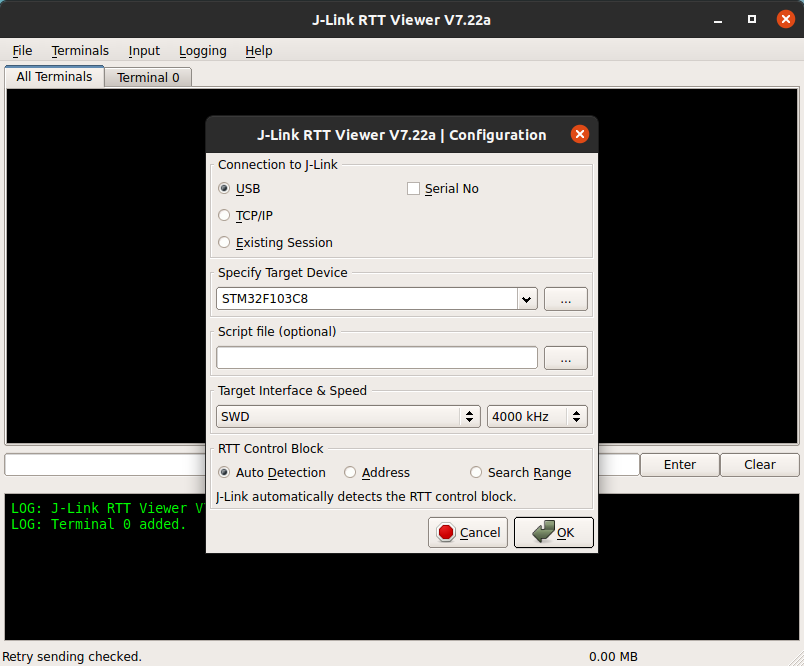
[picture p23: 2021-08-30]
documentation/pictures/JLink/JLinkRTTViewerExe-connect.png

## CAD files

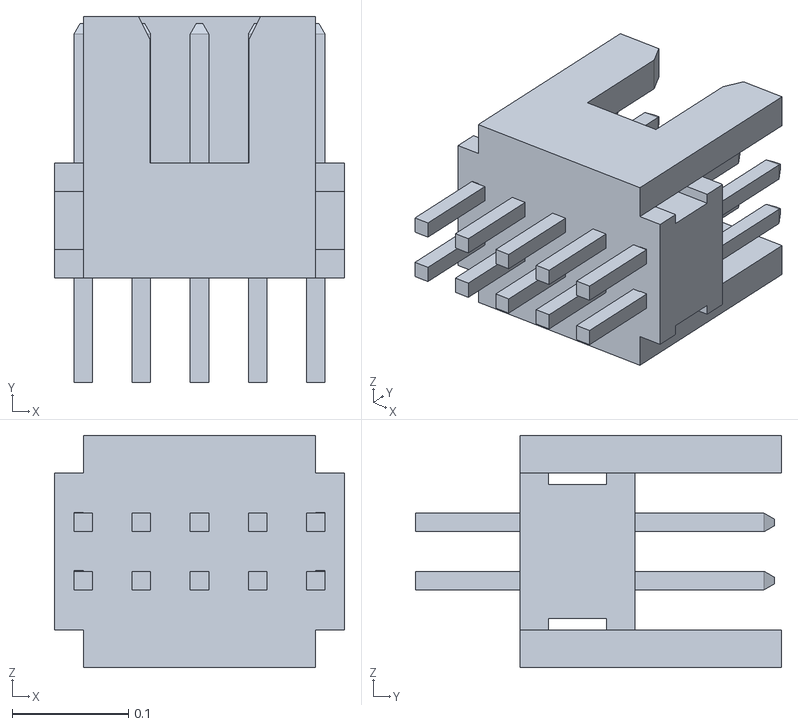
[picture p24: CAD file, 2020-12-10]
hardware/jlink-tagConnect-adapter-v4/Footprints/Models/2x05/FTSH-105-01-L-D-K.stl
0.25 x 0.315 x 0.2

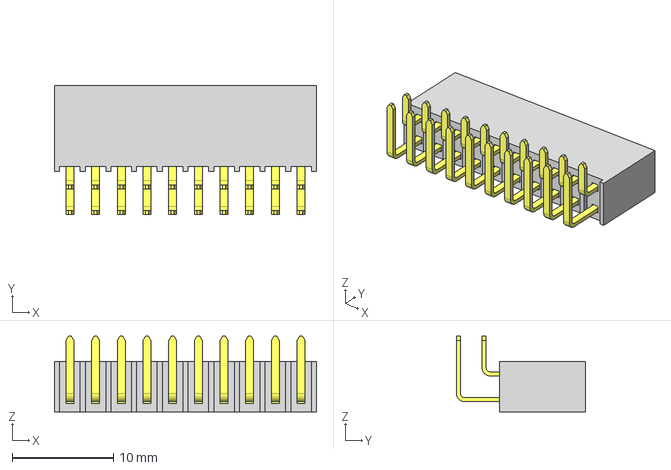
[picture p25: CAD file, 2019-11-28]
hardware/jlink-tagConnect-adapter-v4/Footprints/Models/2x20/samtec/SSW-110-02-L-D-RA.stp
25.9 x 12.8 x 7.48 mm
_T1SSW-110-02-L-D-RA
_P2SSW-110-02-L-D-RA

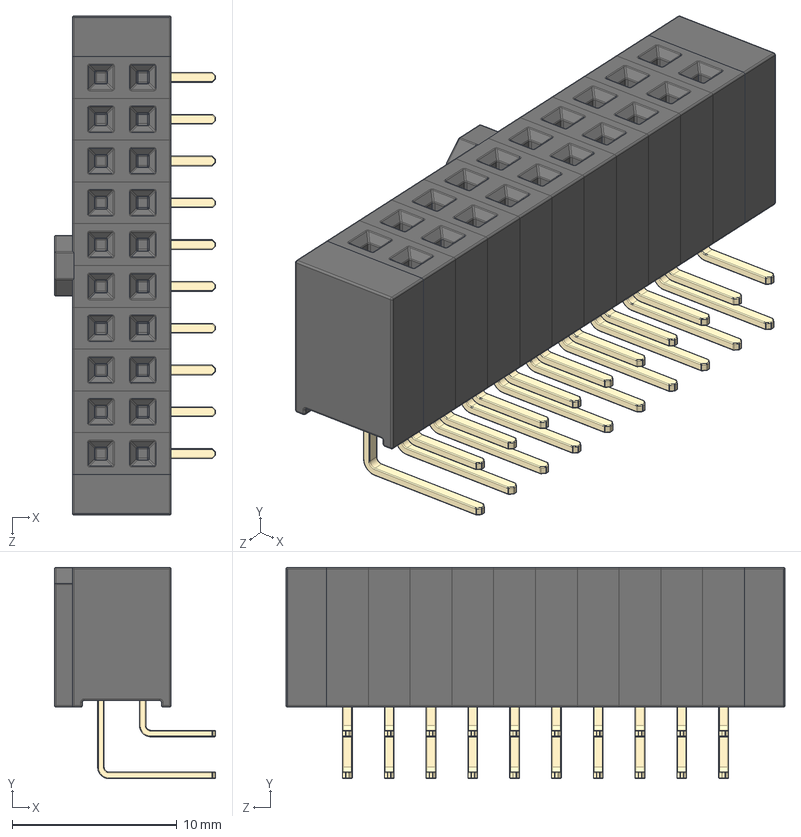
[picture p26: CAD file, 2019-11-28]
hardware/jlink-tagConnect-adapter-v4/Footprints/Models/2x20/SFH11-xxPC-D10-RA-BK.STEP
9.80 x 12.8 x 30.3 mm
body section with RA gold pins x 10
end x 2
Polarizing Key

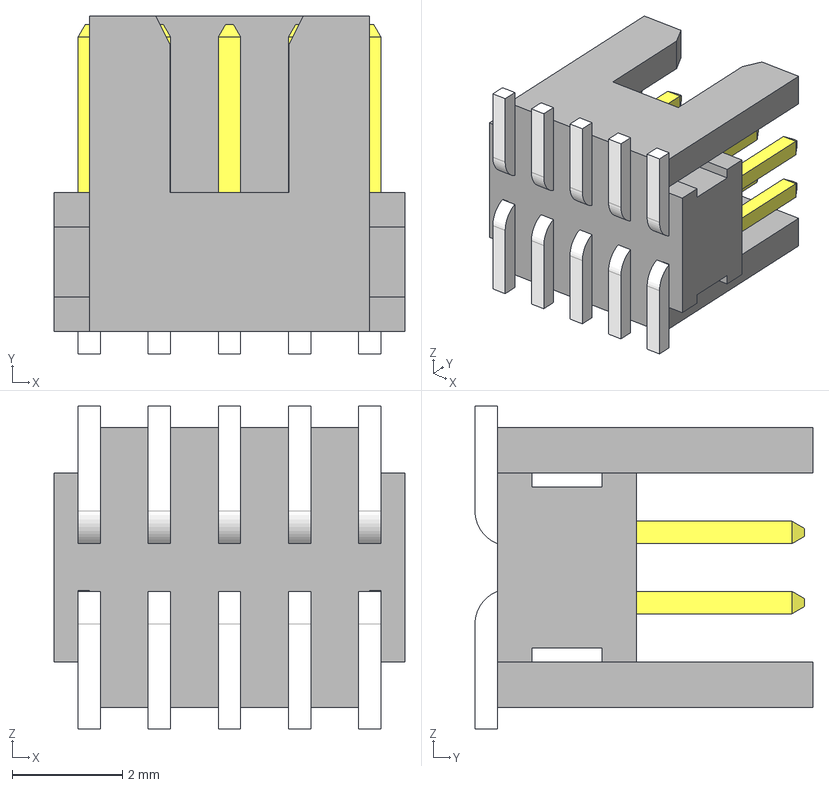
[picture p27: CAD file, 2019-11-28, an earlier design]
hardware/jlink-tagConnect-adapter-v2/Footprints/Models/2x05/FTSH-105-01-L-DV-K.stp
6.35 x 6.12 x 5.84 mm
_FTSH-105-01-L-DV-K_body
_FTSH-105-01-L-DV-K_pins1
_FTSH-105-01-L-DV-K_pins2

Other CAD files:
hardware/jlink-tagConnect-adapter-v2/Footprints/Models/2x05/stl/FTSH-105-01-L-DV-K.stl
hardware/jlink-tagConnect-adapter-v4/Footprints/Models/2x20/samtec/stl/SSW-110-02-L-D-RA.stl

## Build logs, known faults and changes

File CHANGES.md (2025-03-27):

# Modifications made by Licensee (see section 3.4.b)

## Extract from license

**3.4.** The Licensee may communicate to the public and distribute the modified Documentation (thereby in addition to being a Licensee also becoming a Licensor), always provided that he shall:

- **a)** comply with section 3.1;
- **b)** cause the modified Documentation to carry prominent notices stating that the Licensee has modified the Documentation, with the date and description of the modifications;
- **c)** cause the modified Documentation to carry a new Documentation Location notice if the original Documentation provided for one;
- **d)** make available the modified Documentation at the same level of abstraction as that of the Documentation, in the preferred format for making modifications to it (e.g. the native format of the CAD tool as applicable), and in the event that format is proprietary, in a format viewable with a tool licensed under an OSI-approved license if the proprietary tool can create it; and
- **e)** license the modified Documentation under the terms and conditions of this Licence or, where applicable, a later version of this Licence as may be issued by CERN.

<br/>

## Versions

- v1.0: Initial version (Brecht Van Eeckhoudt - 09/2019)
- v2.0: Massive rework to other pinouts (Brecht Van Eeckhoudt - 25/11/2019)
- V3.0: Changed 0.05" header from SMD to through-hole variant, added SWO/TDO disconnect jumper, moved pinout-documentation to the front of the PCB and changed some text, renamed jumpers and moved some other info to the back of the PCB (Brecht Van Eeckhoudt - 11/2020)
- v4.0: Added GND testpoints, a reset button (+ disconnect jumper and footprints for a filter resistor and capacitor) and moved some silk around (Brecht Van Eeckhoudt - 20-07-2024)

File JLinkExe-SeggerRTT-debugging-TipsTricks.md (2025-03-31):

# Segger J-Link debugging tips & tricks

<kbd>[Go back to the adapter information](README.md)</kbd>

<br/>

- [Segger J-Link debugging tips \& tricks](#segger-j-link-debugging-tips--tricks)
  - [1 - J-Link Commander](#1---j-link-commander)
  - [2 - Scripting](#2---scripting)
  - [3 - J-Link Web Control Panel](#3---j-link-web-control-panel)
  - [4 - Debugging using UART vs Segger Real-Time Transfer (RTT)](#4---debugging-using-uart-vs-segger-real-time-transfer-rtt)
    - [4.1 - Why use RTT and how does it work](#41---why-use-rtt-and-how-does-it-work)
    - [4.2 - RTT channels (~buffers) and ROM/RAM usage](#42---rtt-channels-buffers-and-romram-usage)
    - [4.3 - Host-side RTT connection](#43---host-side-rtt-connection)
      - [4.3.1 - J-Link RTT Viewer](#431---j-link-rtt-viewer)
      - [4.3.2 - J-Link RTT Client](#432---j-link-rtt-client)
      - [4.3.3 - J-Link RTT Logger](#433---j-link-rtt-logger)
      - [4.3.4 - Telnet connection](#434---telnet-connection)
      - [4.3.5 - J-Link Web Control Panel](#435---j-link-web-control-panel)
    - [4.4 - Target-side RTT implementation](#44---target-side-rtt-implementation)
      - [4.4.1 - Initialization and configuration](#441---initialization-and-configuration)
      - [4.4.2 - Basic character output](#442---basic-character-output)
      - [4.4.3 - Character output to "virtual" terminals in J-Link RTT Viewer](#443---character-output-to-virtual-terminals-in-j-link-rtt-viewer)
      - [4.4.4 - Formatted strings as output](#444---formatted-strings-as-output)
      - [4.4.5 - Colored output](#445---colored-output)
      - [4.5.6 - Character/value reading (input)](#456---charactervalue-reading-input)

<br/>

## 1 - J-Link Commander

[`JLink.exe/JLinkExe`](https://kb.segger.com/J-Link_Commander) is a simple yet powerful command-line utility which can be very useful in the first stages of getting new hardware working and/or if the programming utility of a software development program doesn't give much feedback on why programming failed. Below is a list of some very useful commands.

<br/>

Some general notes:

- Arguments in `[ ... ]` are optional
- Arguments in `< ... >` need to be filled in with values (`' ... '` denote fixed strings)
- `FileName` expects an absolute path (depending on where `JLink.exe/JLinkExe` is *started*)
- The commands are case-insensitive
- `(hex)` values don't specifically need to be entered with a leading `0x`

<br/>

| (Short) Command | Function | Syntax |
| --- | --- | --- |
| `?` | Show all available commands | `? [<Command>]` |
| `Exit` | Close J-Link connection and quit | |
| `Sleep` | Wait a given time | `Sleep <Delay (ms)>` |
| &nbsp; | | |
| `Connect` `Con` | Establish a target connection | |
| `Device` | Select a device to connect to and perform a reconnect | `Device <DeviceName/'?'>` |
| `SelectInterface` `SI` | Select target interface | `SI <Interface ('SWD'/'JTAG'/...)>` |
| `Speed` | Set target interface speed | `Speed <Freq (kHz)/'auto'/'adaptive'>` |
| &nbsp; | | |
| `Reset` `R` | Reset target chip | |
| `RSetType` `Rst` | Set current reset type | `RSetType [<Type>]` |
| `Halt` `H` | Halt target chip | |
| `IsHalted` `IH` | Check current CPU state (halted/running) | |
| `MoE` | Show mode-of-entry, the reason why the CPU is halted | |
| `Go` `G` | Run target chip | |
| `Step` `S` | Single-step target chip | `Step [<NumSteps (dec)>]` |
| &nbsp; | | |
| `ClrRESET` `R0` | Clear nRESET pin | |
| `SetRESET` `R1` | Set nRESET pin | |
| `ClrTRST` `TRST0` | Clear nTRST pin | |
| `SetTRST` `TRST1` | Set nTRST pin | |
| `ClrTDI` `TDI0` | Clear TDI pin | |
| `SetTDI` `TDI1` | Set TDI pin | |
| &nbsp; | | |
| `Erase` | Erase internal flash or flash range of selected device | `Erase [<SAddr (hex)> <EAddr (hex)>] [<'noreset'/'reset'>]` |
| `LoadFile` | Flash firmware on selected device | `LoadFile <FileName (bin/elf/hex/...)> [<SAddr (for .bin only)>] [<'noreset'/'reset'>]` |
| `SaveBin` | Save target memory range into binary file | `SaveBin <FileName> <SAddr (hex)> <NumBytes (hex)>` |
| `VerifyBin` | Verify if specified bin-file is at specified target memory location | `VerifyBin <FileName> <SAddr (hex)>` |
| &nbsp; | | |
| `Mem` | Read memory of target chip | `Mem [<Zone>:]<SAddr (hex)> <NumBytes (hex)>` |
| `Mem32` | Read memory from target chip in 32-bit units | `Mem32 [<Zone>:]<Addr (hex)> <NumItems (hex)>` |
| `Write4` `W4` | Write 32-bit items to target chip | `Write4 [<Zone>:]<Addr (hex)> <Data (hex)>` |
| `Regs` | Display contents of registers of halted target chip | |
| `RReg` | Read (named) (core) register of target chip | `RReg [<RegName>]` |
| `WReg` | Write (named) (core) register of target chip | `WReg <RegName> <Value (hex)>` |
| `JTagId` `I` | Read JTAG ID of target chip | |
| &nbsp; | | |
| `ShowHWStatus` `ST` | Show debugger hardware status | |
| `ShowFWInfo` `F` | Show debugger firmware info | |
| `ShowConf` `Conf` | Show debugger configuration | |
| `Power` | Switch power supply for target (J-Link 5V-out) | `Power <'On'/'Off'> ['perm']` |
| `VCOM` | Enable/disable VCOM (takes effect after power cycle of J-Link) | `VCOM <'enable'/'disable'>` |
| `VTREF` | Set a fixed mV-value for VTref on J-Link | `VTREF <'0' (= autodetect)/Value (mV)>` |
| &nbsp; | | |
| `TestWSpeed` `TestW` | Measure download speed into target memory | `TestWSpeed [<SAddr (hex)> [<Size (hex)>]]` |
| `TestRSpeed` `TestR` | Measure upload speed from target memory | `TestRSpeed [<SAddr (hex)> [<Size (hex)>] [<NumBlocks (dec)>]]` |
| `TestCSpeed` `TestC` | Measure CPU speed | `TestCSpeed [<RAMAddr (hex)>]` |

<br/>

:pencil: **NOTE:** `JLink.exe/JLinkExe` can be ran using arguments to *bypass* certain steps. An example would be:

```bash
JLinkExe -Device STM32F103C8 -If SWD -Speed auto -AutoConnect 1
```

<br/>

## 2 - Scripting

The above commands can be put in files and subsequently executed to automatically perform, for example, flashing operations. The following sequence connects to a device, flashes firmware to it, resets the target and exits (which lets the firmware start running).

```shell
Device STM32F103C8
SelectInterface SWD
Speed auto

Connect
LoadFile firmware.hex

Reset
Exit
```

The above script can then be executed in for example Powershell, using the following syntax:

```powershell
& 'C:\Program Files\SEGGER\JLink\JLink.exe' -CommandFile firmware-flashing.jlink
```

Replace the path to the actual J-Link installation location. Note that the extension of the scripting-file does not matter.

<br/>

## 3 - J-Link Web Control Panel

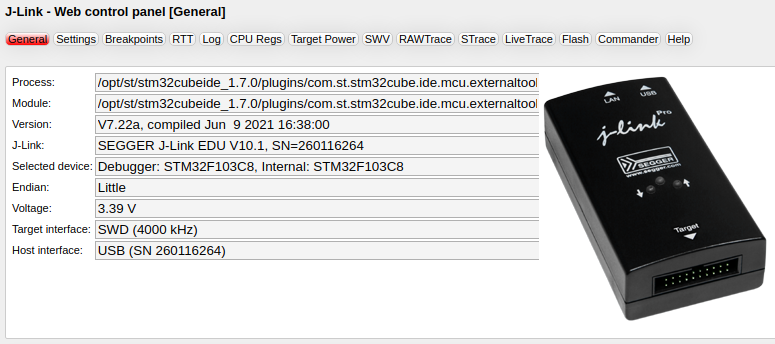
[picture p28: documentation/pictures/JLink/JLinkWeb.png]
J-Link Control Panel


When a J-Link debugger has an active debug session, for instance when it is being used as a programmer or when [`JLinkRTTViewerExe`](https://kb.segger.com/J-Link_RTT_Viewer) is running, the **J-Link Web Control Panel** can be accessed on [http://localhost:19080/](http://localhost:19080/). This can be a very useful and intuitive tool where a lot of settings and functions can be easily accessed. The tab **RTT** can for example be used as a simple RTT-viewer.

<br/>

## 4 - Debugging using UART vs Segger Real-Time Transfer (RTT)

The following sections serve as an introduction and summary of RTT functionality. A lot of the following information was taken from the [Segger RTT Wiki page](https://kb.segger.com/RTT). Refer to this page if more detailed information is required.

<br/>

### 4.1 - Why use RTT and how does it work

Some firmware developers debug using both **breakpoints** and a **UART connection**, the latter of which can be used for real-time code-flow information and displaying variable values. **Using UART however has a few disadvantages**. First of all two extra pin-connections are necessary (`TXD` and `RXD`), alongside the regular debugging pins. Using UART also means one looses an MCU peripheral, some RAM and flash space and precious clock-cycles.
<!-- For a recent project I didn't have a single UART peripheral available for debugging purposes, so I couldn't use my self-written low-level UART debugging library [dbprint](https://github.com/Fescron/dbprint). -->

<!-- I wrote [dbprint](https://github.com/Fescron/dbprint) in a way that it didn't need any external libraries, apart from the MCU-specific UART reading/writing functionality. All of the value-translations, like printing `uint32_t` in *decimal* or *hexadecimal* notation, were done with self-written functions. While it is interesting to understand everything that's going on *under-the-hood*, there are some limitations to this. A lot of time was spend creating the functions and the ability to *port* the code to a different MCU was not really kept in mind from the start. Printing `float` values is up until now also not possible. -->

<!-- Because of the rather MCU-specific [dbprint](https://github.com/Fescron/dbprint) code and the fact that I did not have a spare UART connection for a recent project, I looked for another way to do **printf debugging**. -->

If one searches for other *feedback* mechanisms **Single Wire Output (SWO)** can come to mind. Not all ARM-cores however support this functionality, meaning it is unfortunately not a *one size fits all* solution. If one however has a [Segger J-Link debugger](https://www.segger.com/products/debug-probes/j-link/) it is possible to use [Segger Real-Time Transfer (RTT)](https://www.segger.com/products/debug-probes/j-link/technology/about-real-time-transfer). This supports all target processors which allow background memory access, such as the **Cortex-M** and Renesas RX devices. Support for targets without this functionality (Cortex-A/R and RISC-V) is also being added, be sure to check the [Segger RTT Wiki page (Modes)](https://kb.segger.com/RTT#RTT_operation_Modes) for more information regarding this.

With Segger RTT it is possible to have a very high-speed bidirectional connection to a target device, which can be used to transfer debug information. This can be done **without affecting the MCU's real-time behavior** and **without any additional connections alongside those for programming**. The [RTT implementation code](https://github.com/adfernandes/segger-rtt) writes data to or reads data from special defined memory blocks in the target's memory (*RTT buffers*). These can be found by a J-Link debugger in the target's known RAM regions because the control block contains a special *ID*. The debugger can subsequently read data from and write data to these specific memory blocks, to facilitate the bidirectional connection.

<br/>

### 4.2 - RTT channels (~buffers) and ROM/RAM usage

RTT supports **multiple channels in both directions**, up to the host and down to the target. These can be used for different purposes, such as having a separate *debug* and *error* channel, sending trace information, ... . The default implementation uses one channel per direction (`up/down-channel 0`), which are meant for printable terminal output and input.

Each channel can be configured to be blocking or non-blocking. In **blocking mode** the application will wait when the buffer is full, until all memory could be written and read back by the host (`SEGGER_RTT_MODE_BLOCK_IF_FIFO_FULL`). This results in a blocked application state but prevents data from getting lost. In **non-blocking mode** only data which fits into the buffer (`SEGGER_RTT_MODE_NO_BLOCK_TRIM`, the rest will be discarded), or none at all (`SEGGER_RTT_MODE_NO_BLOCK_SKIP`, the default mode), will be written. This allows **running in real-time, even when no debugger is connected**.

<br/>

The [RTT implementation code](https://github.com/adfernandes/segger-rtt) uses about `500 Bytes` of **ROM**. `24 Bytes` for the ID and `24 Bytes` per channel are required for the control block in **RAM**. Each channel requires some additional **RAM** for the buffer. The recommended  sizes are `1 kByte` (`1024 Bytes`) for *up channels* (the default is `1 kByte`) and `16 - 32 Bytes` for *down channels* (the default is `16 Bytes`). By default a maximum of 3 up/down channels are available and the buffer for bulk-sending chars via RTT (`SEGGER_RTT_printf()`) is `64 Bytes`. All of the default valued can be overridden in the `SEGGER_RTT_Conf.h` file.

<br/>

### 4.3 - Host-side RTT connection

#### 4.3.1 - J-Link RTT Viewer

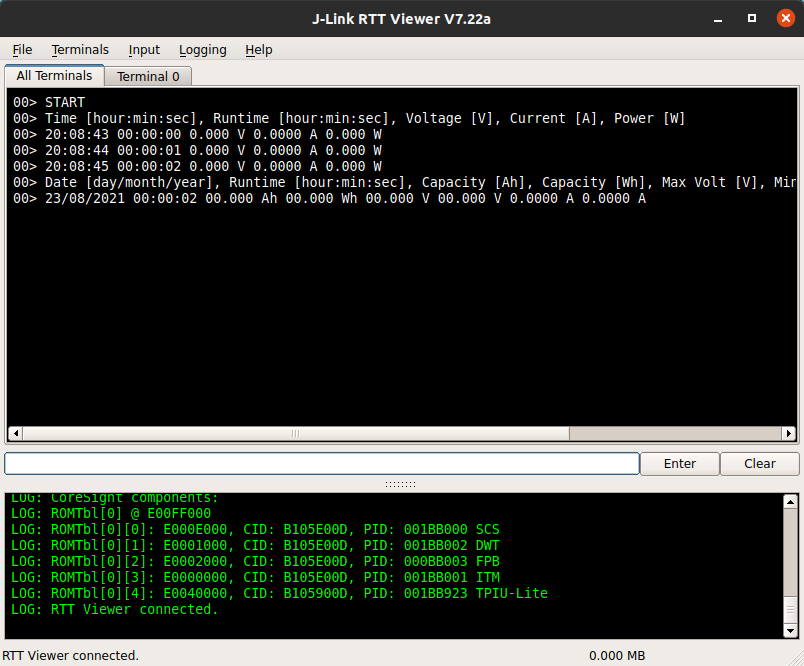
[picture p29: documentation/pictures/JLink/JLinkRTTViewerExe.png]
JLinkRTTViewerExe


[`JLinkRTTViewer.exe/JLinkRTTViewerExe`](https://kb.segger.com/J-Link_RTT_Viewer) is a GUI application which can be used in two modes:

- **Stand-alone mode**, opening a dedicated connection to a J-Link debugger and connected target.
- **Attach mode**, connecting to an existing J-Link connection from either a debug session or **J-Link Commander** and running *parallel* alongside it.
  - Using the argument `-a` or `--autoconnect` when calling `JLinkRTTViewerExe` suppresses the settings popup-dialog and directly selects *attach-mode*.

<br/>

In this application **terminal output** of `Up-Channel 0` is displayed. Additionally up to 16 **virtual Terminals** are possible on `Up-Channel 0`, which can be displayed as separate tabs. The target application can switch between *virtual* terminals with `SEGGER_RTT_SetTerminal()` and `SEGGER_RTT_TerminalOut()`.

Sending **text input** is done to `Down-Channel 0`. The target application can read this with `SEGGER_RTT_GetKey()` and `SEGGER_RTT_Read()`. It can be configured to directly send each character while typing or to buffer it until *Enter* is pressed (*Input -> Sending...*). In **stand-alone mode** the GUI application can retry to send input, in case the target input buffer is full, until all data could be sent to the target (*Input -> Sending... -> Block if FIFO full*).

<br/>

**Terminal output and text input** on `Channel 0` can be **logged**. The format is the same as used in the *All Terminals* tab. Terminal Logging can be started via *Logging -> Start Terminal Logging...*.

**Data output** on `Channel 1` can also be **logged**, for example if an application sends instrumented event tracing data to this channel. The data log file contains a header and footer and the binary data as received from the application. Data Logging can be started via *Logging -> Start Data Logging...*. Note that **Data Logging is only available in stand-alone mode!**

<br/>

- The **All Terminals** tab:
  - Displays the complete output of `Channel 0`
  - Can display the user input (*Input -> Echo input... -> Echo to "All Terminals"*)
  - Prefixes each output line by the *virtual* Terminal it has been sent to
  - Shows output on *virtual* Terminal 1 in red, and output on *virtual*  Terminals 2 - 15 in gray
- The **Terminal 0 - 15** tab:
  - Displays the output which has been sent to the specific *virtual* Terminal
  - Interprets and displays Text Control Codes as sent by the application to show colored text or erase the screen
- The **Terminal 0** tab:
  - Shows by default the output of an RTT application which has not set a Terminal ID
  - Can display the user input (*Input -> Echo input... -> Echo to "Terminal 0"*)

<br/>

The application can also be called with arguments other than `-a` or `--autoconnect`. More information about these can be found on the [Segger RTT Viewer Wiki page (Command line options)](https://kb.segger.com/J-Link_RTT_Viewer#Command_line_options).

<br/>

#### 4.3.2 - J-Link RTT Client

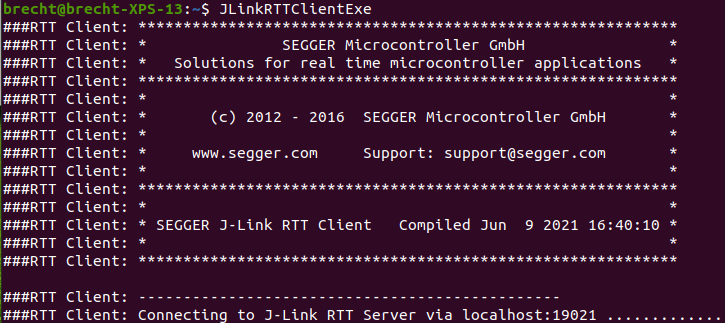
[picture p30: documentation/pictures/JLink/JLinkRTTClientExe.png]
JLinkRTTClientExe


[`JLinkRTTClient.exe/JLinkRTTClientExe`](https://kb.segger.com/J-Link_RTT_Client) is a command-line application which acts as a Telnet client and automatically tries to reconnect to a J-Link connection when a debug session is closed. Communication is done using `Up/Down-Channel 0`. The application **has to be used in parallel** to a existing J-Link connection, thus in tandem with running **J-Link Commander** or with an ongoing debug session.

The application supports a few arguments when called. `-LocalEcho <1/0/On/Off>` enables (which is the default setting) or disables local echo. `-RTTTelnetPort <port>` changes the used port (the default is `19021`).

<br/>

#### 4.3.3 - J-Link RTT Logger

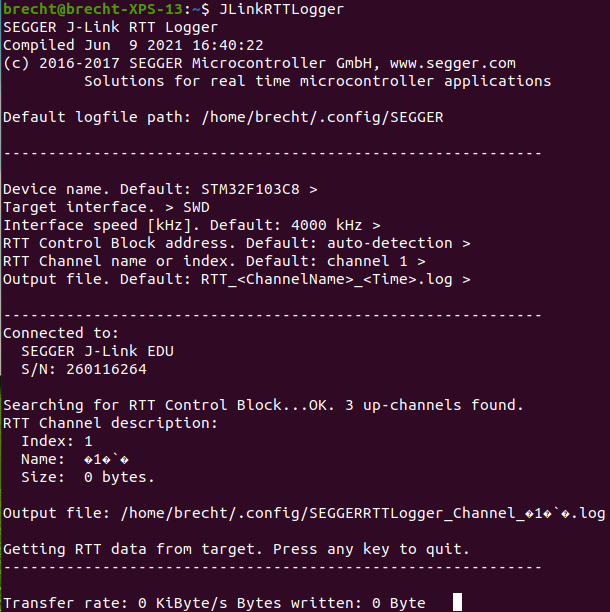
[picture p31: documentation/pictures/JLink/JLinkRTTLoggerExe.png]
JLinkRTTLoggerExe


[`JLinkRTTLogger.exe/JLinkRTTLoggerExe`](https://kb.segger.com/J-Link_RTT_Logger) is a command-line application which opens a dedicated connection to a J-Link debugger and can be used **stand-alone**, without a running debug session. Data from all RTT Up-Channels can be read and logged to a file (but the default is only `Up-Channel 1`).

The application supports a few arguments when called to, for example, directly set the target device or RTT channel. More information about this can be found on the [Segger RTT Logger Wiki page](https://kb.segger.com/J-Link_RTT_Logger).

<br/>
<br/>
<br/>
<br/>
<br/>

#### 4.3.4 - Telnet connection

If a connection to a J-Link debugger is active, for example in the case of an ongoing *debug session* of a target device, a **Telnet client** can be used to (by default) communicate on `Up/Down-Channel 0`. The address the client has to connect to is `localhost:19021`.

The connection will be closed when the connection to the target is closed, for example in case of a debug session being halted. Use the **J-Link RTT Client** to automatically reconnect if a debug session is restarted afterwards.

It is also possible to change the channel, set the *RTT Control Block address* as well as the *RTT Control Block search range* with so called *Segger Telnet Config Strings*. These strings have to be send within `100 ms` after opening the telnet connection. As an example, the string `$$SEGGER_TELNET_ConfigStr=RTTCh;1$$` sets the channel to `Up/Down-Channel 1`. More information about these strings can be found on the [Segger RTT Wiki page (Segger Telnet Config String)](https://kb.segger.com/RTT#SEGGER_TELNET_Config_String).

<br/>

#### 4.3.5 - J-Link Web Control Panel

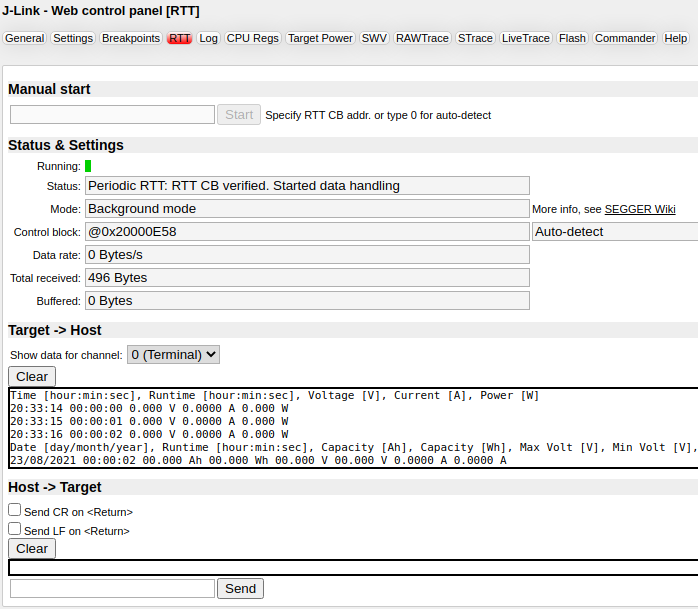
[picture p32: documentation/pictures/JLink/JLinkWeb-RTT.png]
JLinkWeb-RTT


As previously mentioned, the **J-Link Web Control Panel** can be accessed on [http://localhost:19080/](http://localhost:19080/) when a J-Link debugger has an active debug session. The **RTT-tab** can be used as a simple yet intuitive RTT-viewer.

An RTT session can be manually started, and the RTT control block can be both manually entered or auto-detected. It is possible to see the data on *channel 0 (terminal), 1 and 2* and data can also be send from the host to the target device.

<br/>
<br/>
<br/>
<br/>
<br/>

### 4.4 - Target-side RTT implementation

| Quick access links                                                                                       |
| -------------------------------------------------------------------------------------------------------- |
| [Target-side RTT implementation code (unofficial repository)](https://github.com/adfernandes/segger-rtt) |
| [Segger RTT Wiki page (Implementation)](https://wiki.segger.com/RTT#Implementation)                      |

<br/>

The SEGGER RTT implementation is written in *ANSI C* and can be integrated into any embedded application using the code available for download using the above links. It can be used via a simple and easy to use API, which is explained using examples in the following chapters. It is even possible to override the standard `printf()` functions to use RTT, thereby leading to less overhead. A method to write formatted strings is also available (`SEGGER_RTT_Printf()`), which is smaller than most standard library `printf` implementations. Additionally it does not require heap and only a configurable amount of the stack.

The SEGGER RTT implementation is fully configurable with pre-processor defines. Reading and writing can be made task-safe with `SEGGER_RTT_LOCK()` and `SEGGER_RTT_UNLOCK()` routines, to prevent interrupts and task switches from within an RTT operation. The number of buffers as well as the size of the terminal buffers can also be set up easily. Most of this is done in the [`SEGGER_RTT_Conf.h`](https://github.com/adfernandes/segger-rtt/blob/master/Config/SEGGER_RTT_Conf.h) configuration-file.

<br/>

**The following chapters list examples for most of the available functions. Not all of them are covered, please refer to [`SEGGER_RTT.c`](https://github.com/adfernandes/segger-rtt/blob/master/RTT/SEGGER_RTT.c) for every available function.**

<br/>

:warning: **IMPORTANT:** Be sure to always include the Segger RTT header-file when using RTT functionality in source-files:

```C
/* Include Segger RTT functionality (which also includes SEGGER_RTT_Conf.h) */
#include "SEGGER_RTT.h"
```

<br/>

#### 4.4.1 - Initialization and configuration

Because of the way the implementation is written, **generally no initialization and configuration is needed**. Most of the time one can start using RTT printing methods without calling additional configuration functions. In some cases it is however useful to initialize RTT manually or change some of the underlying functionality, so examples for some of the available methods are described in the following paragraphs.

```C
/** Automatically initialize RTT and also to clear the screen and reposition 
  * the cursor to the top-left */
SEGGER_RTT_WriteString(0, RTT_CTRL_CLEAR);

/** Initialize RTT Control Block structure
  *  - This is generally used when using RAM only targets and should then be called 
  *    at the start of the application
  *  - In most other cases this is automatically called by the RTT methods */
SEGGER_RTT_Init();
```

<br/>

*Output/up buffer 0* is configured during compile-time. The following function-calls can change the behavior if the buffer is full. These are the so-called **buffer flags**.

:pencil: **NOTE:** `int`, returned by the RTT functions and assumed to be 32-bits in size, is not explicitly casted to `int8_t` but the returned values should fit according to the underlying code.

```C
/** Configure output/up buffer 0 (first parameter) in non-blocking-skip mode
  *  - The application does not wait, all data is lost if the FIFO-buffer is full
  *  - This is the default mode
  *  - Returns "0" if the configuration was successful or "-1" if an error occurred */
int8_t result = SEGGER_RTT_SetFlagsUpBuffer(0, SEGGER_RTT_MODE_NO_BLOCK_SKIP);

/** Configure output/up buffer 0 (first parameter) in non-blocking-trim mode
  *  - The application does not wait, data which can't fit is lost if the FIFO-buffer is full
  *  - Returns "0" if the configuration was successful or "-1" if an error occurred */
int8_t result = SEGGER_RTT_SetFlagsUpBuffer(0, SEGGER_RTT_MODE_NO_BLOCK_TRIM);

/** Configure output/up buffer 0 (first parameter) in blocking mode
  *  - The application waits if necessary, no data is lost
  *  - Returns "0" if the configuration was successful or "-1" if an error occurred */
int8_t result = SEGGER_RTT_SetFlagsUpBuffer(0, SEGGER_RTT_MODE_BLOCK_IF_FIFO_FULL);
```

<br/>

:pencil: **NOTE:** The RAM regions or the specific address of the Control Block can also be set via the **host** applications to speed up detection or if the block cannot be found automatically.

<br/>

#### 4.4.2 - Basic character output

Below are a few examples on how to facilitate basic character output.

:pencil: **NOTE:** `int`, returned by the RTT functions and assumed to be 32-bits in size, is not explicitly casted to `uint8_t` but the returned values should fit according to the underlying code.

```C
/** Clear the screen and reposition the cursor to the top-left (RTT_CTRL_CLEAR), 
  * print a zero-terminated (\0) string/character array to output/up-buffer 0 
  * (first parameter), return the carriage and go to the next line (/r/n)
  *  - Internally calls "SEGGER_RTT_Write" after the length of the string is calculated
  *  - Returns the number of bytes stored in the up-buffer
  *  - Data is stored according to buffer flags */
uint32_t bytes = SEGGER_RTT_WriteString(0, RTT_CTRL_CLEAR"Text goes here\r\n");

/** Same as above but now using a character array */
char    text[] = "Text goes here\r\n";
uint32_t bytes = SEGGER_RTT_WriteString(0, text);

/** Print a specified number of bytes to output/up-buffer 0 (first parameter)
  *  - A pointer to a character array (second parameter) and its size in bytes 
  *   (third parameter) need to be given
  *  - Returns the number of bytes stored in the up-buffer 
  *  - Internally calls "SEGGER_RTT_WriteNoLock"
  *  - Data is stored according to buffer flags */
char character = 'A';
uint32_t bytes = SEGGER_RTT_Write(0, &character, 1);

/** Same as above but does not lock the application so interrupts can be handled
  *  - Does not call initialization functionality and may only be called after 
  *    RTT has been initialized, either by calling SEGGER_RTT_Init() or calling 
  *    another RTT API function first 
  *  - Data is stored according to buffer flags */
char character = 'A';
uint32_t bytes = SEGGER_RTT_WriteNoLock(0, &character, 1);

/** Print a single character to output/up-buffer 0 (first parameter)
  *  - Returns the number of bytes stored in the up-buffer
  *  - Data is stored according to buffer flags */
uint8_t bytes = SEGGER_RTT_PutChar(0, 'a');
```

<br>

#### 4.4.3 - Character output to "virtual" terminals in J-Link RTT Viewer

When using **J-Link RTT Viewer** to capture the RTT messages, some methods are available to change the *(virtual) Terminal* to which data is send. This is internally done using specific sequences which are interpreted by the J-Link RTT Viewer. Other applications like a Telnet Client will ignore them.

:pencil: **NOTE:** `int`, returned by the RTT functions and assumed to be 32-bits in size, is not explicitly casted to `int8_t` but the returned values should fit according to the underlying code.

```C
/** Change the "virtual" terminal on channel 0 to show all following "Write",
  * "WriteString" or "printf" outputs to "1" ("0" - "F" are all correct options) 
  *  - Returns "0" if the configuration was successful or "-1" if an error occurred */
int8_t result = SEGGER_RTT_SetTerminal(1);

/** Print a zero-terminated (\0) string/character array to a specific "virtual" terminal,
  * in this case "1", on output/up-buffer 0, return the carriage and 
  * go to the next line (/r/n)
  *  - If the returned value is >= 0 then it equals the amount of bytes stored 
  *    in the up-buffer
  *  - Returns "-1" if an error occurred */
int32_t result = SEGGER_RTT_TerminalOut(1, "Text goes here\r\n");
```

<br/>

#### 4.4.4 - Formatted strings as output

Below are some basic examples to print formatted strings as output.

```C
/** Print an unsigned integer value (%u) and signed integer value (%d) to 
  * output/up-buffer 0 (first parameter), return the carriage
  * and go to the next line (/r/n)
  *  - Internally calls "SEGGER_RTT_vprintf" and eventually "SEGGER_RTT_Write"
  *  - If result >= 0 then it equals the amount of bytes stored in the up-buffer
  *  - If result < 0 then an error occurred
  *  - Data is stored according to buffer flags */
uint32_t uValue = 42;
int32_t  sValue = -42;
int32_t  result = SEGGER_RTT_printf(0, "uValue = %u, sValue = %d\r\n", uValue, sValue);

/** Print a hexadecimal integer value (%x) to output/up-buffer 0 (first parameter),
  * return the carriage and go to the next line (/r/n)
  *  - This does not print the leading "0x"
  *  - Internally calls "SEGGER_RTT_vprintf" and eventually "SEGGER_RTT_Write"
  *  - If result >= 0 then it equals the amount of bytes stored in the up-buffer
  *  - If result < 0 then an error occurred
  *  - Data is stored according to buffer flags */
uint32_t value = 0xFF;
int32_t result = SEGGER_RTT_printf(0, "Value = %x\r\n", value);

/** Print a hexadecimal integer value with 8-digits (%p) to output/up-buffer 0 
  * (first parameter), return the carriage and go to the next line (/r/n)
  *  - This does not print the leading "0x"
  *  - Internally calls "SEGGER_RTT_vprintf" and eventually "SEGGER_RTT_Write"
  *  - If result >= 0 then it equals the amount of bytes stored in the up-buffer
  *  - If result < 0 then an error occurred
  *  - Data is stored according to buffer flags */
uint32_t value = 0x000000FF;
int32_t result = SEGGER_RTT_printf(0, "Value = %p\r\n", value);

/** Print a character (%c) to output/up-buffer 0 (first parameter),
  * return the carriage and go to the next line (/r/n)
  *  - Internally calls "SEGGER_RTT_vprintf" and eventually "SEGGER_RTT_Write"
  *  - If result >= 0 then it equals the amount of bytes stored in the up-buffer
  *  - If result < 0 then an error occurred
  *  - Data is stored according to buffer flags */
char character = 'a';
int32_t result = SEGGER_RTT_printf(0, "Character = %c\r\n", character);

/** Print a string (%s) to output/up-buffer 0 (first parameter),
  * return the carriage and go to the next line (/r/n)
  *  - Internally calls "SEGGER_RTT_vprintf" and eventually "SEGGER_RTT_Write"
  *  - If result >= 0 then it equals the amount of bytes stored in the up-buffer
  *  - If result < 0 then an error occurred
  *  - Data is stored according to buffer flags */
char    text[] = "Text goes here";
int32_t result = SEGGER_RTT_printf(0, "Text = %s\r\n", text);
```

<br/>

Below there are some more advanced examples to print formatted strings as output.

```C
/** Print a signed integer value (%d) to output/up-buffer 0 (first parameter) 
  * and always print the sign-extension (+), return the carriage and go
  * to the next line (/r/n)
  *  - Internally calls "SEGGER_RTT_vprintf" and eventually "SEGGER_RTT_Write"
  *  - If result >= 0 then it equals the amount of bytes stored in the up-buffer
  *  - If result < 0 then an error occurred
  *  - Data is stored according to buffer flags */
int32_t value  = 42;
int32_t result = SEGGER_RTT_printf(0, "Value = %+d\r\n", value);

/** Print an unsigned integer value (%u) to output/up-buffer 0 (first parameter)
  * and make sure the value-field always has a width of 4 characters (4),
  * return the carriage and go to the next line (/r/n)
  *  - Internally calls "SEGGER_RTT_vprintf" and eventually "SEGGER_RTT_Write"
  *  - If result >= 0 then it equals the amount of bytes stored in the up-buffer
  *  - If result < 0 then an error occurred
  *  - Data is stored according to buffer flags */
uint32_t value = 42;
int32_t result = SEGGER_RTT_printf(0, "Value = %4u\r\n", value);

/** Print an unsigned integer value (%u) to output/up-buffer 0 (first parameter),
  * make sure the value-field always has a width of 4 characters (4),
  * use zeros instead of spaces for padding (0), return the carriage 
  * and go to the next line (/r/n)
  *  - Internally calls "SEGGER_RTT_vprintf" and eventually "SEGGER_RTT_Write"
  *  - If result >= 0 then it equals the amount of bytes stored in the up-buffer
  *  - If result < 0 then an error occurred
  *  - Data is stored according to buffer flags */
uint32_t value = 42;
int32_t result = SEGGER_RTT_printf(0, "Value = %04u\r\n", value);

/** Print an unsigned integer value (%u) to output/up-buffer 0 (first parameter),
  * make sure the value-field always has a width of 4 characters (.4)
  * (add leading zeros if necessary), return the carriage
  * and go to the next line (/r/n)
  *  - Internally calls "SEGGER_RTT_vprintf" and eventually "SEGGER_RTT_Write"
  *  - If result >= 0 then it equals the amount of bytes stored in the up-buffer
  *  - If result < 0 then an error occurred
  *  - The flag "0" (pad with zeros instead of spaces) is ignored when used
  *    in combination with "precision" (._)
  *  - Data is stored according to buffer flags */
uint32_t value = 42;
int32_t result = SEGGER_RTT_printf(0, "Value = %.4u\r\n", value);

/** Print an unsigned integer value (%u) to output/up-buffer 0 (first parameter),
  * make sure the value-field always has a width of 4 characters (4),
  * left-justify within the field width (-), return the carriage
  * and go to the next line (/r/n)
  *  - Internally calls "SEGGER_RTT_vprintf" and eventually "SEGGER_RTT_Write"
  *  - If result >= 0 then it equals the amount of bytes stored in the up-buffer
  *  - If result < 0 then an error occurred
  *  - The flag "0" (pad with zeros instead of spaces) is ignored when used
  *    in combination with the flag "-"
  *  - Data is stored according to buffer flags */
uint32_t value = 42;
int32_t result = SEGGER_RTT_printf(0, "Value = %-4u\r\n", value);
```

<br/>

#### 4.4.5 - Colored output

Text and/or values can be given a specific color with the following *color control sequences*:

- `RTT_CTRL_RESET` Reset the text- and background color.
- `RTT_CTRL_TEXT_xxx` Set the **text** color to one of the following colors:
  - `BLACK`, `RED`, `GREEN`, `YELLOW`, `BLUE`, `MAGENTA`, `CYAN`, `WHITE` (light grey)
  - `BRIGHT_BLACK` (dark grey), `BRIGHT_RED`, `BRIGHT_GREEN`, `BRIGHT_YELLOW`, `BRIGHT_BLUE`, `BRIGHT_MAGENTA`, `BRIGHT_CYAN`, `BRIGHT_WHITE`
- `RTT_CTRL_BG_xxx` Set the **background** color to one of the previously listed colors.

<br/>

Below are two examples with colored text using the methods `SEGGER_RTT_WriteString` and `SEGGER_RTT_printf`, both of which use the *color control sequences* slightly different.

```C
/** Print some colored text to output/up-buffer 0 (first parameter)
  * and go to the next line (/r/n)
  *  - Internally calls "SEGGER_RTT_Write" and eventually "SEGGER_RTT_WriteNoLock"
  *  - Returns the number of bytes stored in the up-buffer
  *  - Data is stored according to buffer flags */
uint32_t result = SEGGER_RTT_WriteString(0,
        RTT_CTRL_RESET"Red: " \
        RTT_CTRL_TEXT_BRIGHT_RED"This text is red. " \
        RTT_CTRL_TEXT_BLACK"" \
        RTT_CTRL_BG_BRIGHT_RED"This background is red. " \
        RTT_CTRL_RESET"Normal text again.\r\n"
    );

/** Same as above but using another method
  *  - Internally calls "SEGGER_RTT_vprintf" and eventually "SEGGER_RTT_Write"
  *  - If result >= 0 then it equals the amount of bytes stored in the up-buffer
  *  - If result < 0 then an error occurred
  *  - Data is stored according to buffer flags */
int32_t result = SEGGER_RTT_printf(0, 
        "%sRed: %sThis text is red. %s%sThis background is red. %sNormal text again.\r\n",
        RTT_CTRL_RESET,
        RTT_CTRL_TEXT_BRIGHT_RED,
        RTT_CTRL_TEXT_BLACK,
        RTT_CTRL_BG_BRIGHT_RED,
        RTT_CTRL_RESET
    );
```

<br/>

#### 4.5.6 - Character/value reading (input)

:pencil: **NOTE:** `int`, returned by the RTT functions and assumed to be 32-bits in size, is not explicitly casted to `uint8_t`/`int16_t` but the returned values should fit according to the underlying code.

```C
/** Wait for (at least one) character, previously stored by the host, to be available 
  * in input/down-buffer 0 and return it ("0" - "255")
  *  - Internally calls "SEGGER_RTT_GetKey" until a character is received */
uint8_t character = SEGGER_RTT_WaitKey();

/** Read one character, previously stored by the host, from input/down-buffer 0
  * and return it ("0" - "255")
  *  - Returns "-1" if no character is available (buffer empty) (uint8_t => uint16_t)
  *  - Internally calls "SEGGER_RTT_READ" */
int16_t character = SEGGER_RTT_GetKey();

/** Check if at least one character, previously stored by the host, 
  * is available in input/down-buffer 0
  *  - Returns "0" if no characters are available 
  *  - Returns "1" if at least one character is available */
uint8_t result = SEGGER_RTT_HasKey();

/** Reads characters, previously stored by the host, from input/down buffer 0 
  * (first parameter)
  *  - A pointer to a buffer to store the characters (second parameter) and its size 
  *    in bytes (third parameter) (1 char = 1 byte) need to be given
  *  - Returns the number of bytes which have been read
  *  - Internally calls "SEGGER_RTT_ReadNoLock" */
uint32_t characters = "";
uint32_t bytes = SEGGER_RTT_Read(0, &characters, 4);

/* Same as above but does not lock the application so interrupts can be handled */
uint32_t characters = "";
uint32_t bytes = SEGGER_RTT_ReadNoLock(0, &characters, 4);

/** Check if there is data, previously stored by the host, 
  * available in input/down-buffer 0 (first parameter)
  *  - Returns "0" if no data is available in the buffer */
int8_t result = SEGGER_RTT_HasData(0);
```

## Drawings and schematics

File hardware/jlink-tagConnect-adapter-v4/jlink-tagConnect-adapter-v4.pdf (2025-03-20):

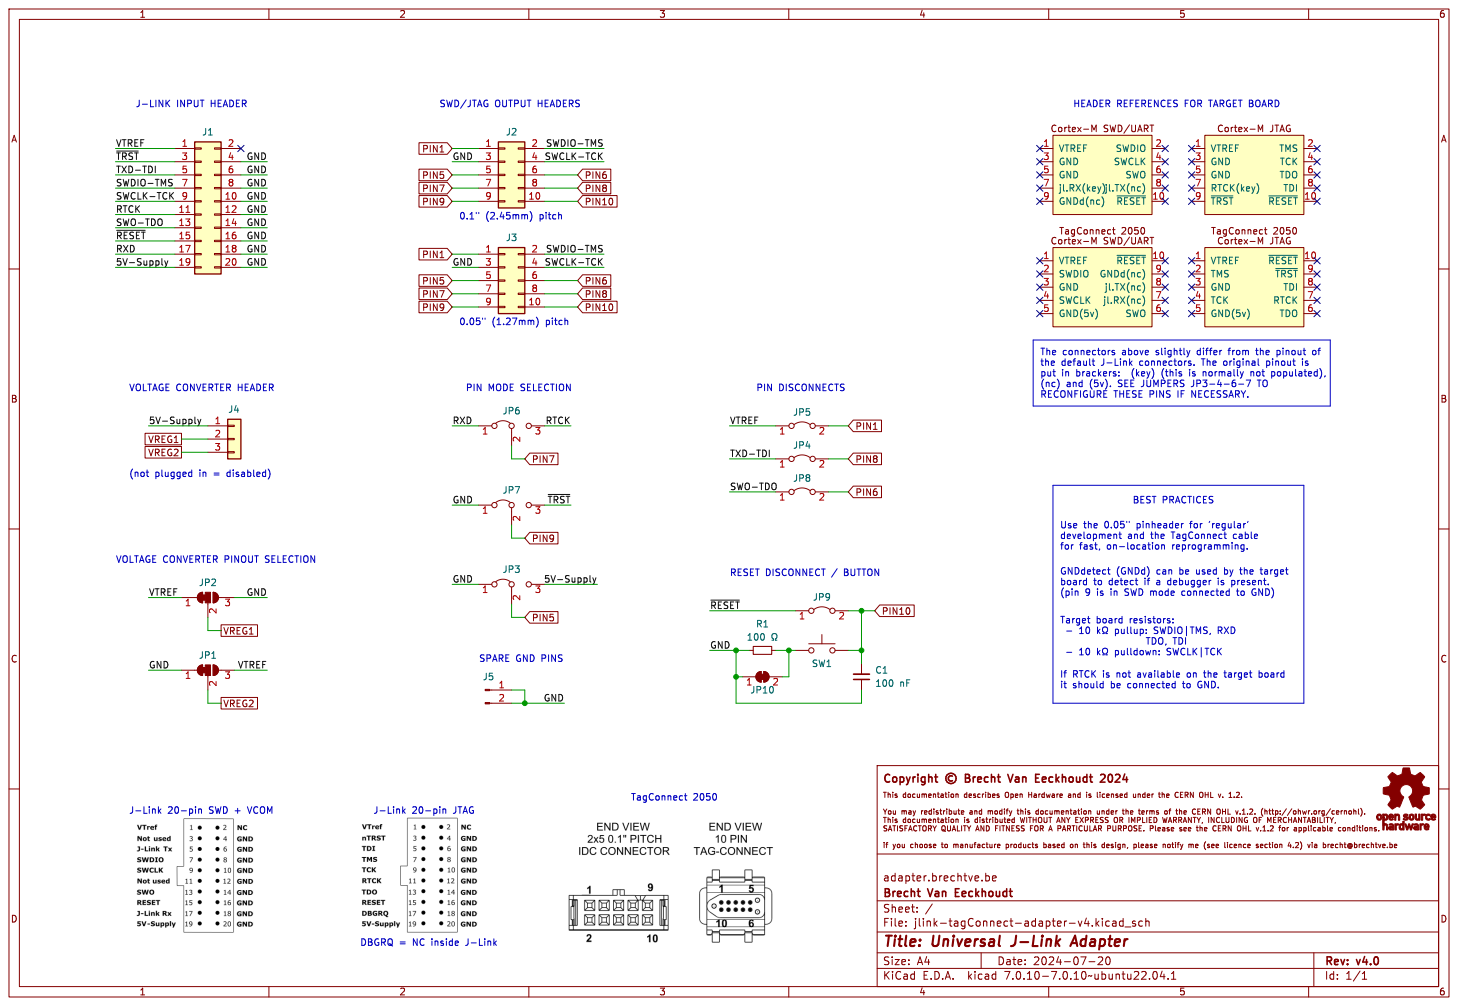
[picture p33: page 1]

SWD/JTAG OUTPUT HEADERS
~{TRST} SWCLK-TCK

TXD-TDI ~{TRST} VTREF RXD

SWDIO-TMS GND GND GND GND GND

TXD-TDI SWCLK-TCK
SWDIO-TMS

RECONFIGURE THESE PINS IF NECESSARY. DBGRQ = NC inside J-Link

VOLTAGE CONVERTER PINOUT SELECTION

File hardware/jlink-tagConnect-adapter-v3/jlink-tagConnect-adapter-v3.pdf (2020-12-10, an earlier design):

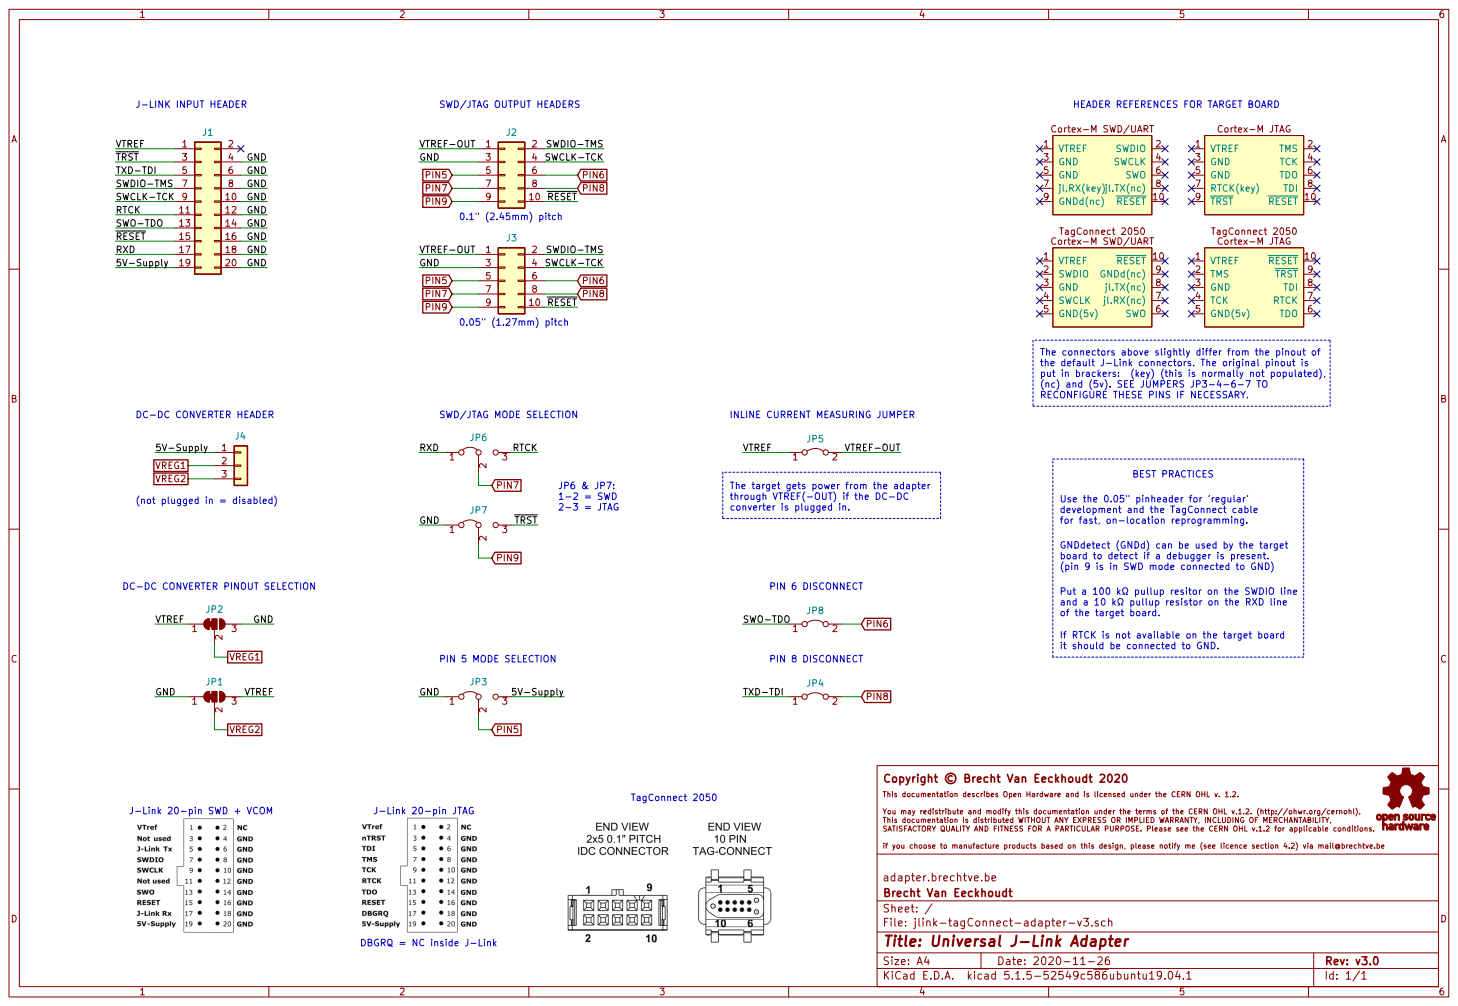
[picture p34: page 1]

SWD/JTAG OUTPUT HEADERS

HEADER REFERENCES FOR TARGET BOARD

RESET VTREF
TXD-TDI SWDIO-TMS

TXD-TDI GNDGND GND GND GND

0.05" (1.27mm) pitch SWD/JTAG MODE SELECTION

The connectors above slightly differ from the pinout of
the default J-Link connectors. The original pinout is
put in brackers: (key) (this is normally not populated),
(nc) and (5v). SEE JUMPERS JP3-4-6-7 TO
RECONFIGURE THESE PINS IF NECESSARY. Use the 0.05" pinheader for 'regular'

(not plugged in = disabled) DC-DC CONVERTER HEADER

INLINE CURRENT MEASURING JUMPER

for fast, on-location reprogramming. BEST PRACTICES

The target gets power from the adapter
through VTREF(-OUT) if the DC-DC
converter is plugged in.

development and the TagConnect cable

it should be connected to GND. GNDdetect (GNDd) can be used by the target
board to detect if a debugger is present.

(pin 9 is in SWD mode connected to GND) PIN 6 DISCONNECT

DC-DC CONVERTER PINOUT SELECTION

Put a 100 k pullup resitor on the SWDIO line
and a 10 k pullup resistor on the RXD line
of the target board.

If RTCK is not available on the target board

Copyright © Brecht Van Eeckhoudt 2020

J-Link 20-pin SWD + VCOM

This documentation describes Open Hardware and is licensed under the CERN OHL v. 1.2.

You may redistribute and modify this documentation under the terms of the CERN OHL v.1.2. (http://ohwr.org/cernohl).

File: jlink-tagConnect-adapter-v3.sch Sheet: / Brecht Van Eeckhoudt adapter.brechtve.be

Id: 1/1 Title: Universal J-Link Adapter

DBGRQ = NC inside J-Link

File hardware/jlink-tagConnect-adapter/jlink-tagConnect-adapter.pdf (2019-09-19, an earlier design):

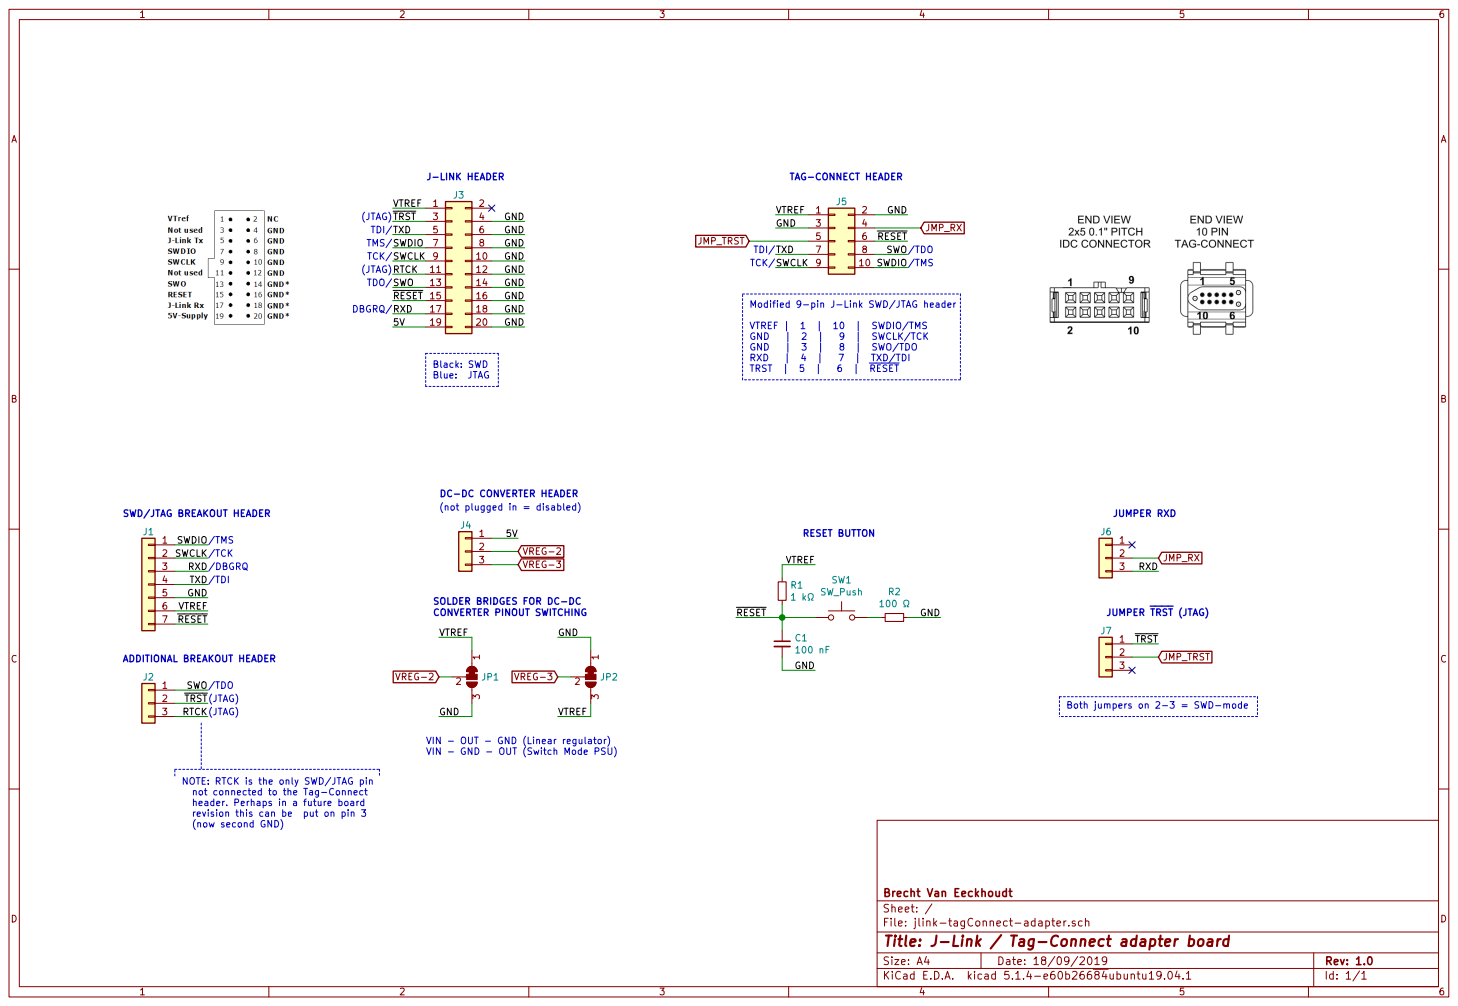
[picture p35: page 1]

Modified 9-pin J-Link SWD/JTAG header

Both jumpers on 2-3 = SWD-mode RESET BUTTON
VTREF GND

SOLDER BRIDGES FOR DC-DC
CONVERTER PINOUT SWITCHING
VTREF

VIN - OUT - GND (Linear regulator)

NOTE: RTCK is the only SWD/JTAG pin
not connected to the Tag-Connect
header. Perhaps in a future board
revision this can be put on pin 3
(now second GND)

File: jlink-tagConnect-adapter.sch Sheet: / Brecht Van Eeckhoudt

Id: 1/1 Title: J-Link / Tag-Connect adapter board

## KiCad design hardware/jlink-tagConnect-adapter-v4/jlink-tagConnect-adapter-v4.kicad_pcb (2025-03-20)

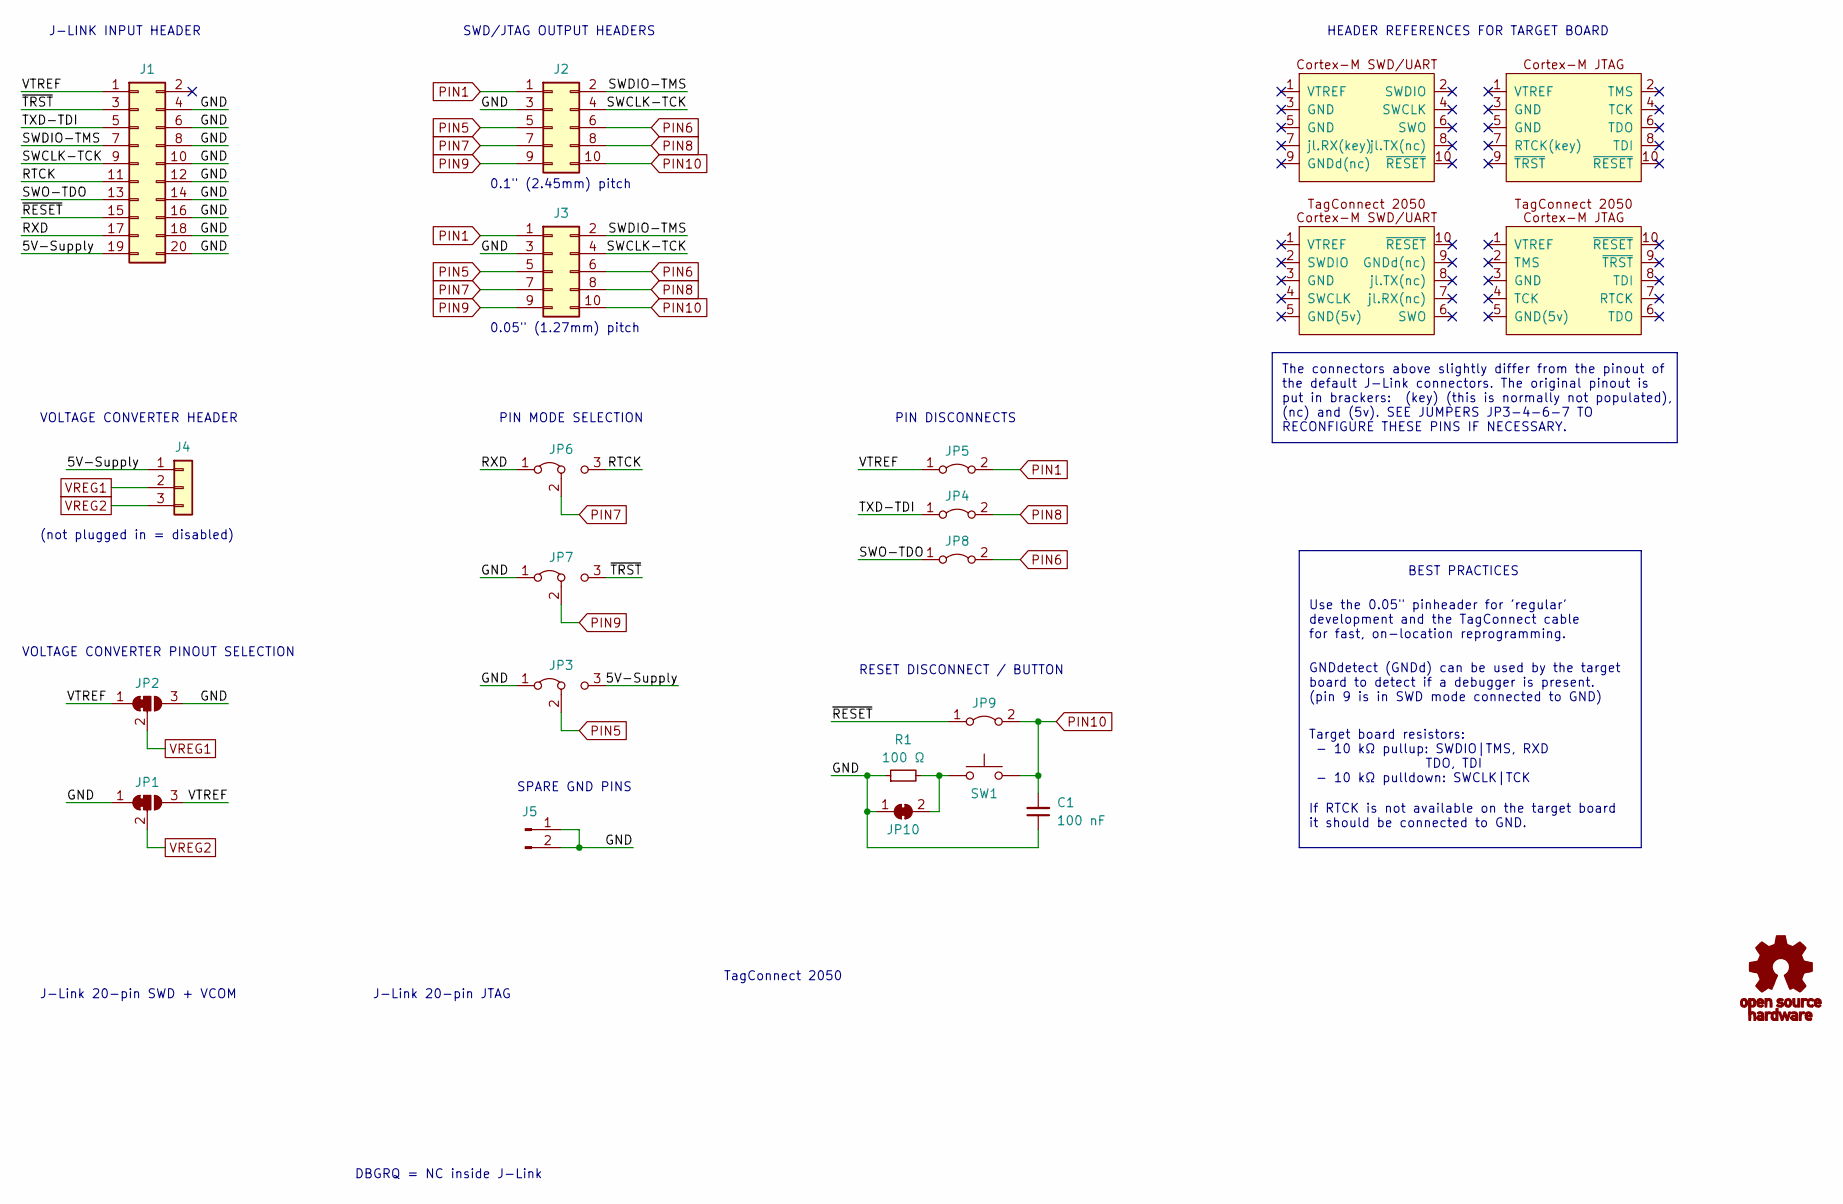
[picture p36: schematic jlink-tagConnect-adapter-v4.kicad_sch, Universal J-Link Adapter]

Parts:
C1: 100 nF; C_0603_1608Metric_Pad1.08x0.95mm_HandSolder
G1: Symbol_OSHW-Logo_11.4x12mm; OSHW-Logo_5.7x6mm_SolderMask
J1: Conn_02x10_Odd_Even; PinSocket_2x10_P2.54mm_Horizontal
J2: Conn_02x05_Odd_Even; IDC-Header_2x05_P2.54mm_Vertical
J3: Conn_02x05_Odd_Even; PinHeader_2x05_P1.27mm_Vertical
J4: Conn_01x03; PinSocket_1x03_P2.54mm_Vertical
J5: Conn_01x02_Pin; PinHeader_1x02_P2.54mm_Vertical
JP1, JP2: SolderJumper_3_Bridged12; SolderJumper-3_P1.3mm_Bridged12_Pad1.0x1.5mm_NumberLabels
JP3, JP6, JP7: Jumper_3_Bridged12; PinHeader_1x03_P2.54mm_Vertical
JP4, JP5, JP8, JP9: Jumper_2_Bridged; PinHeader_1x02_P2.54mm_Vertical
JP10: SolderJumper_2_Bridged; SolderJumper-2_P1.3mm_Bridged_Pad1.0x1.5mm
R1: 100 Ω; R_0603_1608Metric_Pad0.98x0.95mm_HandSolder
SW1: SW_Push; SW_PUSH_1P1T_6x3.5mm_H4.3_APEM_MJTP1243

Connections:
/5V-Supply: J1.19, J4.1, JP3.3 (B)
/GND: C1.1, J1.4, J1.6, J1.8, J1.10, J1.12, J1.14, J1.16, J1.18, J1.20, J2.3, J3.3, J5.1, J5.2, JP1.1 (A), JP2.3 (B), JP3.1 (A), JP7.1 (A), JP10.1 (A), R1.1
/RTCK: J1.11, JP6.3 (B)
/RXD: J1.17, JP6.1 (A)
/SWCLK-TCK: J1.9, J2.4, J3.4
/SWDIO-TMS: J1.7, J2.2, J3.2
/SWO-TDO: J1.13, JP8.1 (A)
/TXD-TDI: J1.5, JP4.1 (A)
/VTREF: J1.1, JP1.3 (B), JP2.1 (A), JP5.1 (A)
/~RESET: J1.15, JP9.1 (A)
/~TRST: J1.3, JP7.3 (B)
unnamed: JP10.2 (B), R1.2, SW1.1
PIN1: J2.1, J3.1, JP5.2 (B)
PIN5: J2.5, J3.5, JP3.2 (C)
PIN6: J2.6, J3.6, JP8.2 (B)
PIN7: J2.7, J3.7, JP6.2 (C)
PIN8: J2.8, J3.8, JP4.2 (B)
PIN9: J2.9, J3.9, JP7.2 (C)
PIN10: C1.2, J2.10, J3.10, JP9.2 (B), SW1.2
VREG1: J4.2, JP2.2 (C)
VREG2: J4.3, JP1.2 (C)

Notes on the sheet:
(not plugged in = disabled)
VOLTAGE CONVERTER PINOUT SELECTION
TagConnect 2050
GNDdetect (GNDd) can be used by the target board to detect if a debugger is present. (pin 9 is in SWD mode connected to GND)
0.1" (2.45mm) pitch
PIN DISCONNECTS
0.05" (1.27mm) pitch
SPARE GND PINS
BEST PRACTICES
RESET DISCONNECT / BUTTON
PIN MODE SELECTION
DBGRQ = NC inside J-Link
The connectors above slightly differ from the pinout of the default J-Link connectors. The original pinout is put in brackers: (key) (this is normally not populated), (nc) and (5v). SEE JUMPERS JP3-4-6-7 TO RECONFIGURE THESE PINS IF NECESSARY.
SWD/JTAG OUTPUT HEADERS
J-Link 20-pin JTAG
J-LINK INPUT HEADER
HEADER REFERENCES FOR TARGET BOARD
VOLTAGE CONVERTER HEADER
If RTCK is not available on the target board it should be connected to GND.
Use the 0.05" pinheader for 'regular' development and the TagConnect cable for fast, on-location reprogramming.
J-Link 20-pin SWD + VCOM
Target board resistors: - 10 kΩ pullup: SWDIO|TMS, RXD TDO, TDI - 10 kΩ pulldown: SWCLK|TCK

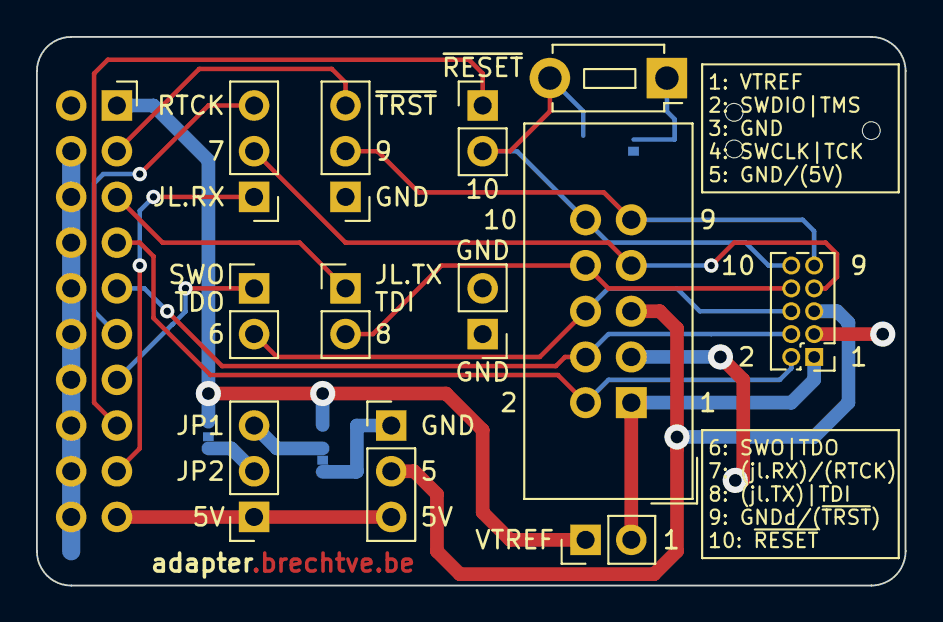
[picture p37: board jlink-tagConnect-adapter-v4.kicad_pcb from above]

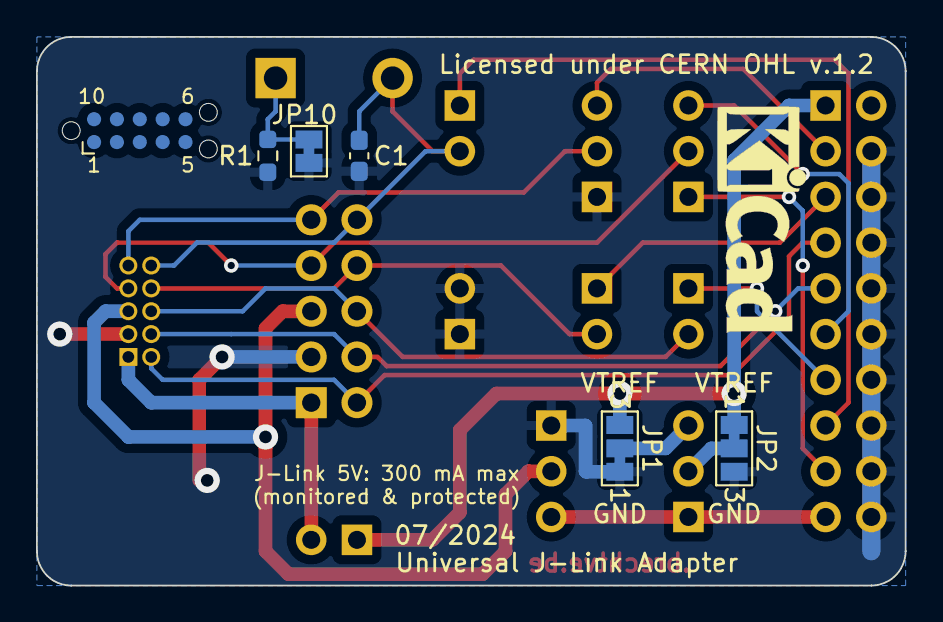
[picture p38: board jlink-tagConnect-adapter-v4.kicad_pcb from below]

Board: 2 copper layers, 48.3 x 30.5 mm, 19 parts (6 on the bottom side), 21 nets.

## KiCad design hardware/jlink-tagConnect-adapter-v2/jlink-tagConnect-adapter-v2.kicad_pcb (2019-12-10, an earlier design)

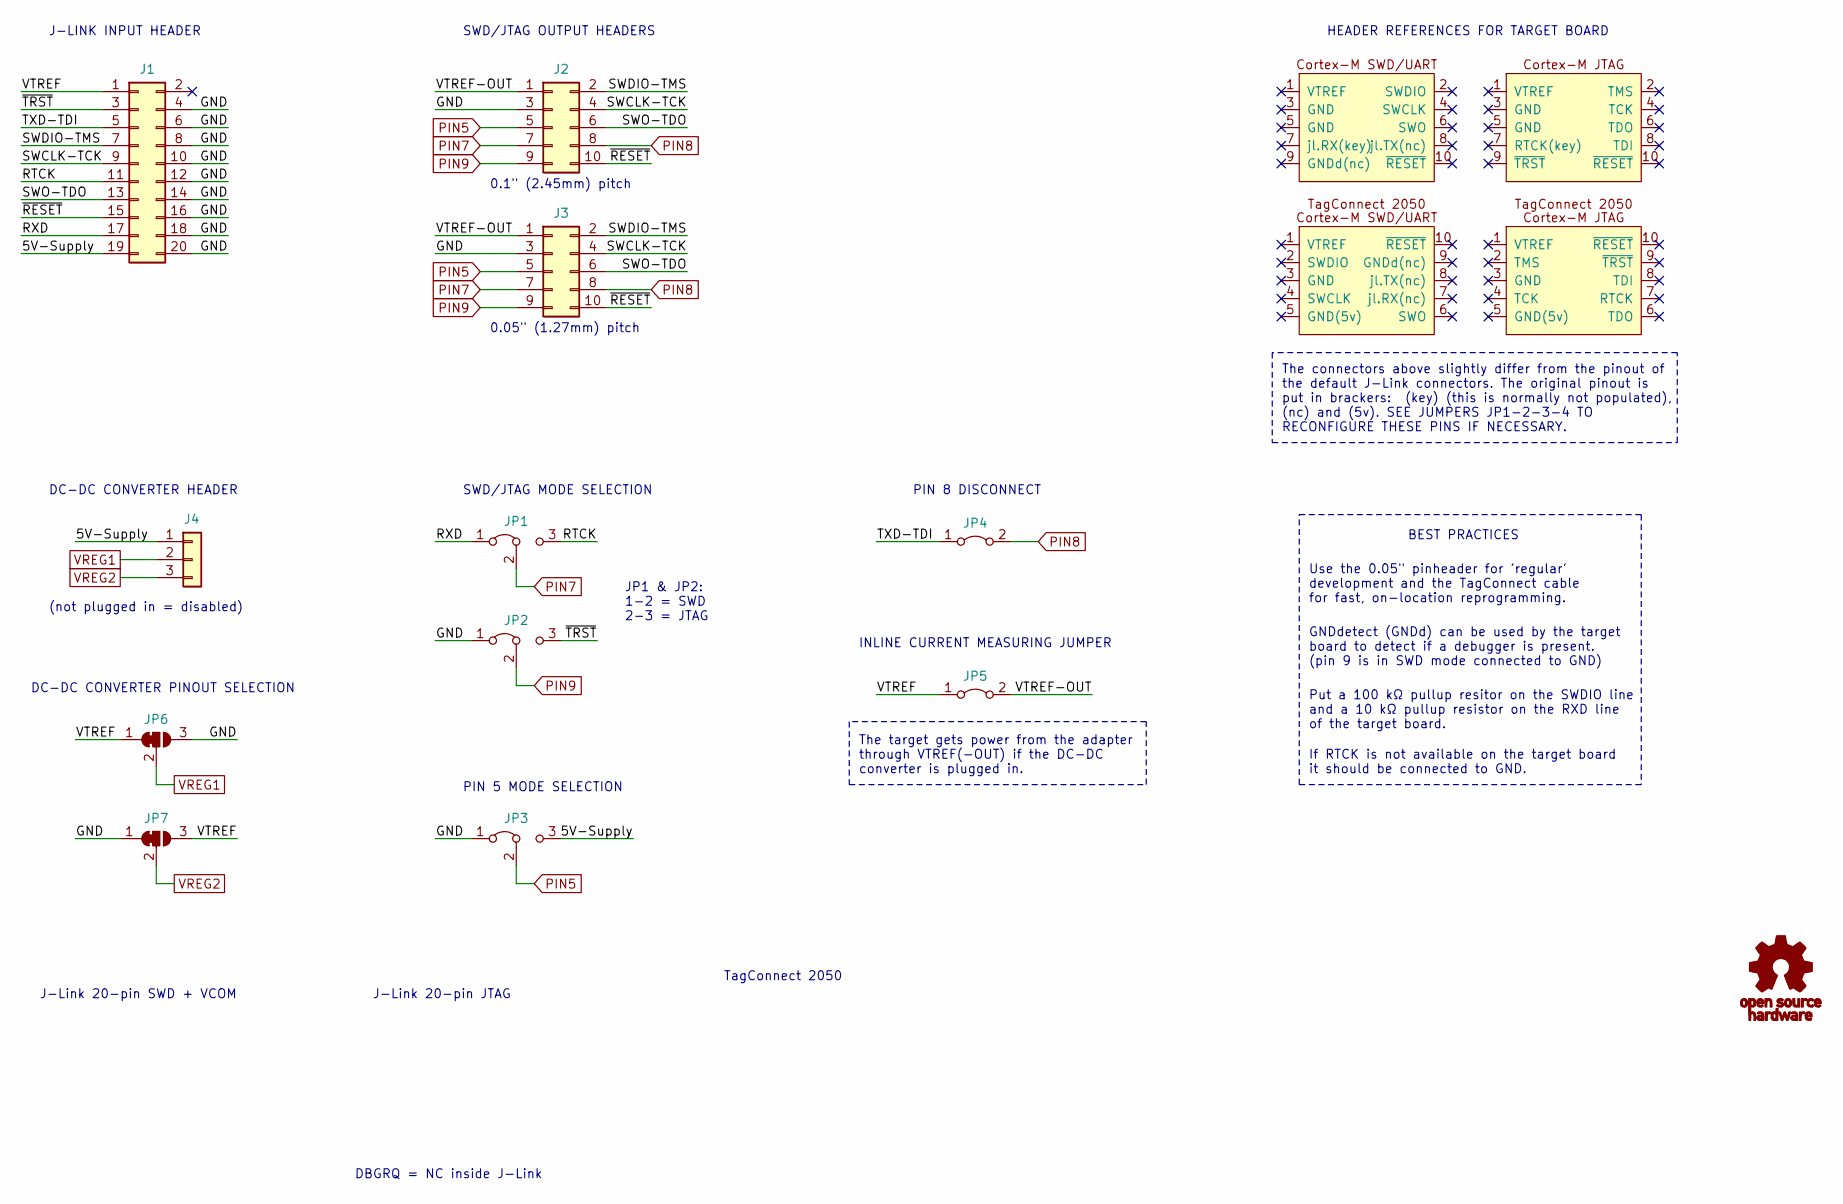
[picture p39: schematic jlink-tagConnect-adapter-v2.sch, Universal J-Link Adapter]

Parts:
G1: Symbol_OSHW-Logo_11.4x12mm; OSHW-Logo_5.7x6mm_SolderMask
J1: Conn_02x10_Odd_Even; PinSocket_2x10_P2.54mm_Horizontal
J2: Conn_02x05_Odd_Even; IDC-Header_2x05_P2.54mm_Vertical
J3: Conn_02x05_Odd_Even; PinHeader_2x05_P1.27mm_Vertical_SMD
J4: Conn_01x03; PinSocket_1x03_P2.54mm_Vertical
JP1, JP2, JP3: Jumper_3_Bridged12; PinHeader_1x03_P2.54mm_Vertical
JP4, JP5: Jumper_2_Bridged; PinHeader_1x02_P2.54mm_Vertical
JP6, JP7: SolderJumper_3_Bridged12; SolderJumper-3_P1.3mm_Bridged12_Pad1.0x1.5mm_NumberLabels

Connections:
/5V-Supply: J1.19, J4.1, JP3.3 (B)
/GND: J1.4, J1.6, J1.8, J1.10, J1.12, J1.14, J1.16, J1.18, J1.20, J2.3, J3.3, JP2.1 (A), JP3.1 (A), JP6.3 (B), JP7.1 (A)
/RTCK: J1.11, JP1.3 (B)
/RXD: J1.17, JP1.1 (A)
/SWCLK-TCK: J1.9, J2.4, J3.4
/SWDIO-TMS: J1.7, J2.2, J3.2
/SWO-TDO: J1.13, J2.6, J3.6
/TXD-TDI: J1.5, JP4.1 (A)
/VTREF: J1.1, JP5.1 (A), JP6.1 (A), JP7.3 (B)
/VTREF-OUT: J2.1, J3.1, JP5.2 (B)
/~RESET: J1.15, J2.10, J3.10
/~TRST: J1.3, JP2.3 (B)
PIN5: J2.5, J3.5, JP3.2 (C)
PIN7: J2.7, J3.7, JP1.2 (C)
PIN8: J2.8, J3.8, JP4.2 (B)
PIN9: J2.9, J3.9, JP2.2 (C)
VREG1: J4.2, JP6.2 (C)
VREG2: J4.3, JP7.2 (C)

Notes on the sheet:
J-Link 20-pin JTAG
J-Link 20-pin SWD + VCOM
DBGRQ = NC inside J-Link
J-LINK INPUT HEADER
HEADER REFERENCES FOR TARGET BOARD
TagConnect 2050
0.1" (2.45mm) pitch
0.05" (1.27mm) pitch
SWD/JTAG OUTPUT HEADERS
SWD/JTAG MODE SELECTION
JP1 & JP2: 1-2 = SWD 2-3 = JTAG
INLINE CURRENT MEASURING JUMPER
DC-DC CONVERTER HEADER
(not plugged in = disabled)
Use the 0.05" pinheader for 'regular' development and the TagConnect cable for fast, on-location reprogramming.
BEST PRACTICES
Put a 100 kΩ pullup resitor on the SWDIO line and a 10 kΩ pullup resistor on the RXD line of the target board.
If RTCK is not available on the target board it should be connected to GND.
GNDdetect (GNDd) can be used by the target board to detect if a debugger is present. (pin 9 is in SWD mode connected to GND)
The connectors above slightly differ from the pinout of the default J-Link connectors. The original pinout is put in brackers: (key) (this is normally not populated), (nc) and (5v). SEE JUMPERS JP1-2-3-4 TO RECONFIGURE THESE PINS IF NECESSARY.
The target gets power from the adapter through VTREF(-OUT) if the DC-DC converter is plugged in.
PIN 5 MODE SELECTION
PIN 8 DISCONNECT
DC-DC CONVERTER PINOUT SELECTION

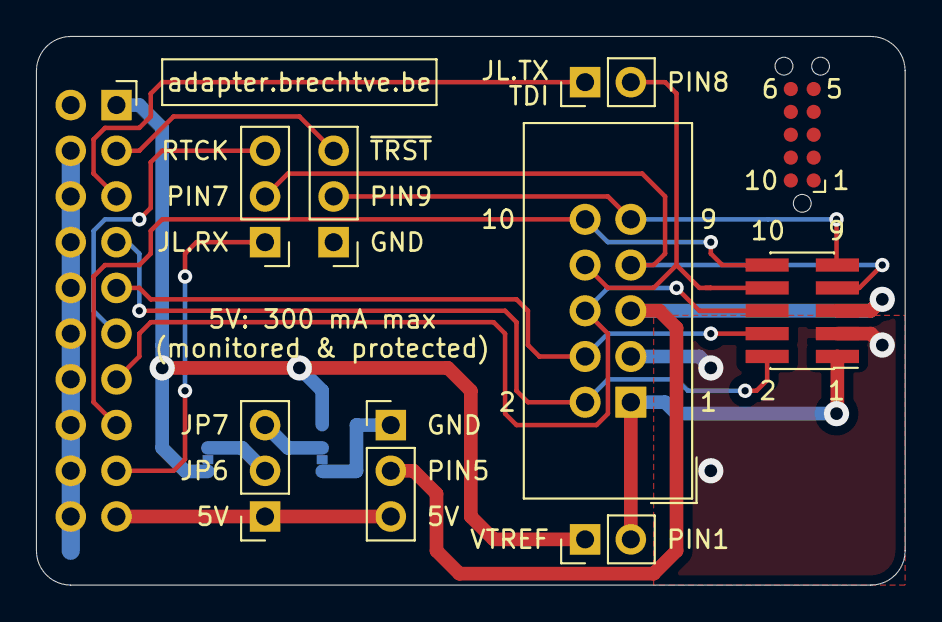
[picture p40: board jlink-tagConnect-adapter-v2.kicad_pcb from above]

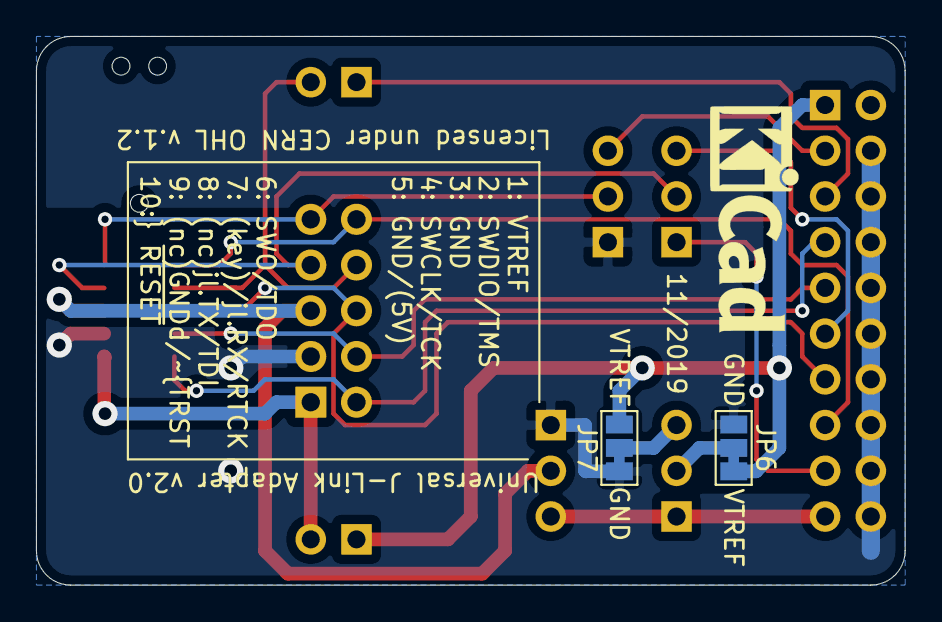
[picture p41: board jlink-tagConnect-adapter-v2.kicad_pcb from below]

Board: 2 copper layers, 48.3 x 30.5 mm, 12 parts (2 on the bottom side), 18 nets.

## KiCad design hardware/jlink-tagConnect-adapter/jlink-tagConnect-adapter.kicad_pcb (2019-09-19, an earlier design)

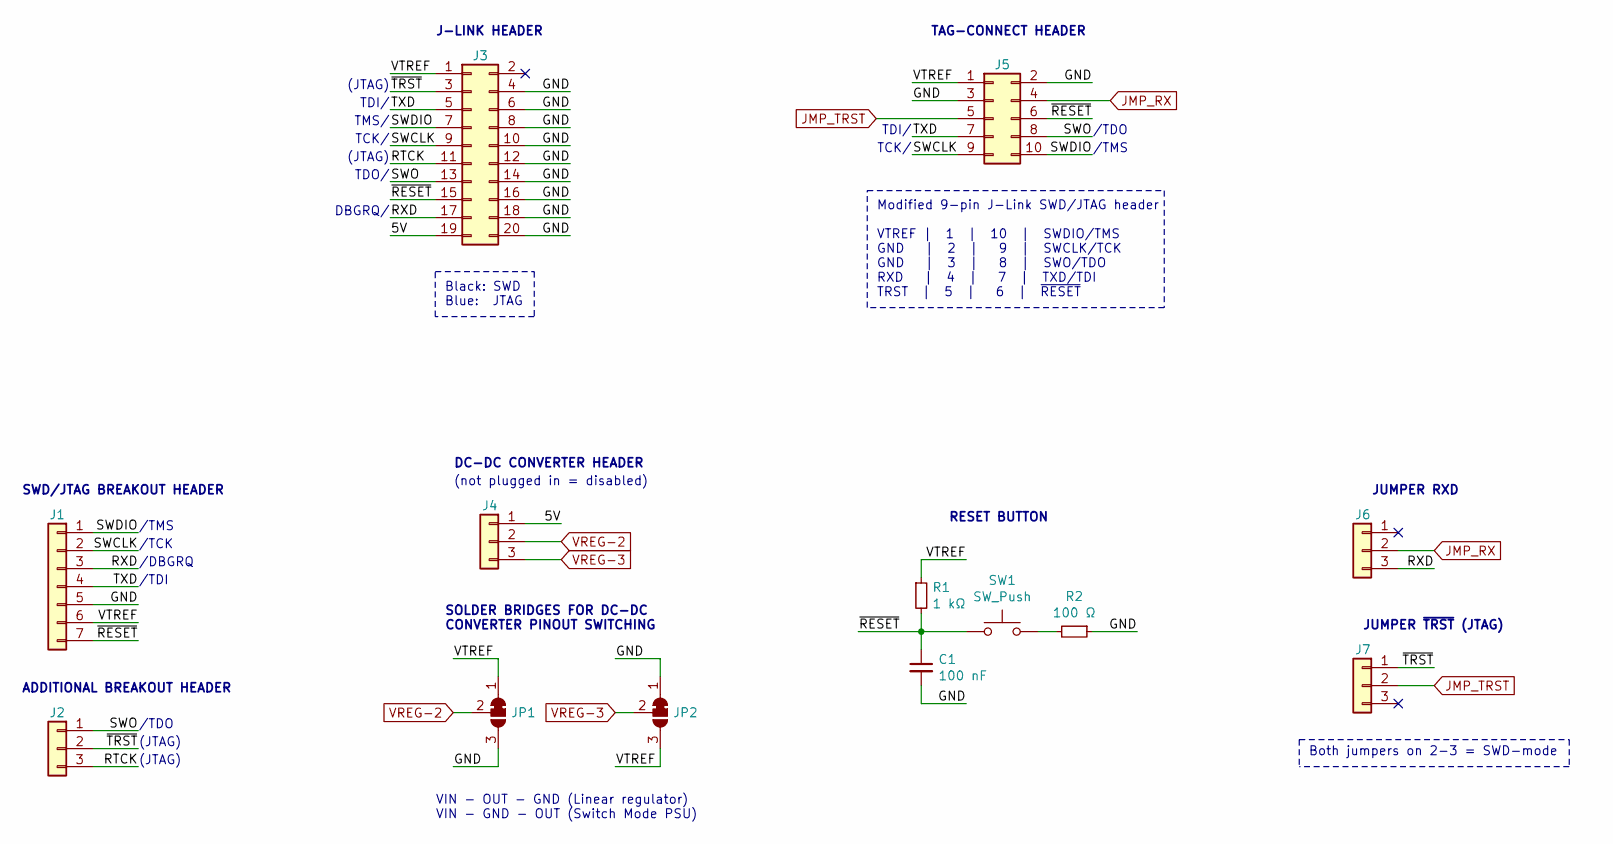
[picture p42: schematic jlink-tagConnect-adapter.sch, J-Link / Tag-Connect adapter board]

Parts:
C1: 100 nF; C_0805_2012Metric_Pad1.15x1.40mm_HandSolder
J1: Conn_01x07; PinHeader_1x07_P2.54mm_Vertical
J2, J6, J7: Conn_01x03; PinHeader_1x03_P2.54mm_Vertical
J3: Conn_02x10_Odd_Even; PinSocket_2x10_P2.54mm_Horizontal
J4: Conn_01x03; PinSocket_1x03_P2.54mm_Vertical
J5: Conn_02x05_Odd_Even; IDC-Header_2x05_P2.54mm_Vertical
JP1, JP2: SolderJumper_3_Bridged12; SolderJumper-3_P1.3mm_Bridged12_Pad1.0x1.5mm_NumberLabels
R1: 1 kΩ; R_0805_2012Metric_Pad1.15x1.40mm_HandSolder
R2: 100 Ω; R_0805_2012Metric_Pad1.15x1.40mm_HandSolder
SW1: SW_Push; SW_SPST_FSMSM

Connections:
/5V: J3.19, J4.1
/GND: C1.2, J1.5, J3.4, J3.6, J3.8, J3.10, J3.12, J3.14, J3.16, J3.18, J3.20, J5.2, J5.3, JP1.3 (B), JP2.1 (A), R2.1
/RTCK: J2.3, J3.11
/RXD: J1.3, J3.17, J6.3
/SWCLK: J1.2, J3.9, J5.9
/SWDIO: J1.1, J3.7, J5.10
/SWO: J2.1, J3.13, J5.8
/TXD: J1.4, J3.5, J5.7
/VTREF: J1.6, J3.1, J5.1, JP1.1 (A), JP2.3 (B), R1.1
/~RESET: C1.1, J1.7, J3.15, J5.6, R1.2, SW1.1
/~TRST: J2.2, J3.3, J7.1
JMP_RX: J5.4, J6.2
JMP_TRST: J5.5, J7.2
unnamed: R2.2, SW1.2
VREG-2: J4.2, JP1.2 (C)
VREG-3: J4.3, JP2.2 (C)

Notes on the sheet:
JUMPER RXD
/TDO
/TMS
TCK/
TDI/
TDO/
TMS/
DBGRQ/
Black: SWD Blue: JTAG
(JTAG)
JUMPER ~TRST~ (JTAG)
RESET BUTTON
SWD/JTAG BREAKOUT HEADER
VIN - OUT - GND (Linear regulator) VIN - GND - OUT (Switch Mode PSU)
ADDITIONAL BREAKOUT HEADER
/TCK
/DBGRQ
/TDI
Modified 9-pin J-Link SWD/JTAG header VTREF | 1 | 10 | SWDIO/TMS GND | 2 | 9 | SWCLK/TCK GND | 3 | 8 | SWO/TDO RXD | 4 | 7 | TXD/TDI TRST | 5 | 6 | ~RESET
TAG-CONNECT HEADER
SOLDER BRIDGES FOR DC-DC CONVERTER PINOUT SWITCHING
Both jumpers on 2-3 = SWD-mode
J-LINK HEADER
DC-DC CONVERTER HEADER
(not plugged in = disabled)

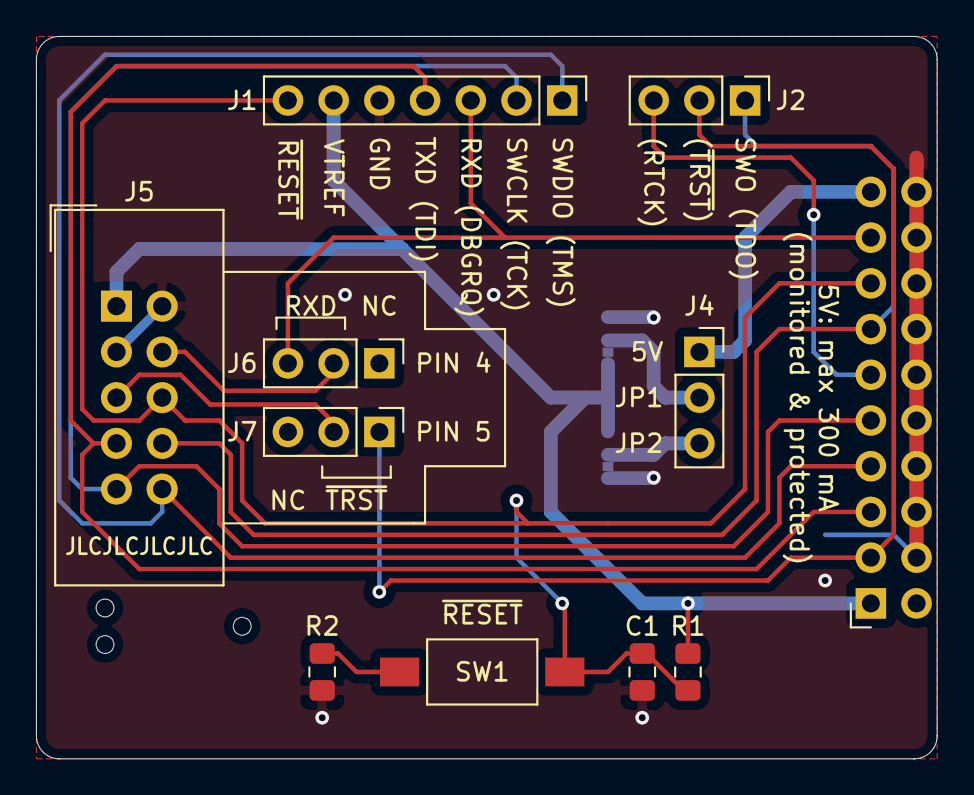
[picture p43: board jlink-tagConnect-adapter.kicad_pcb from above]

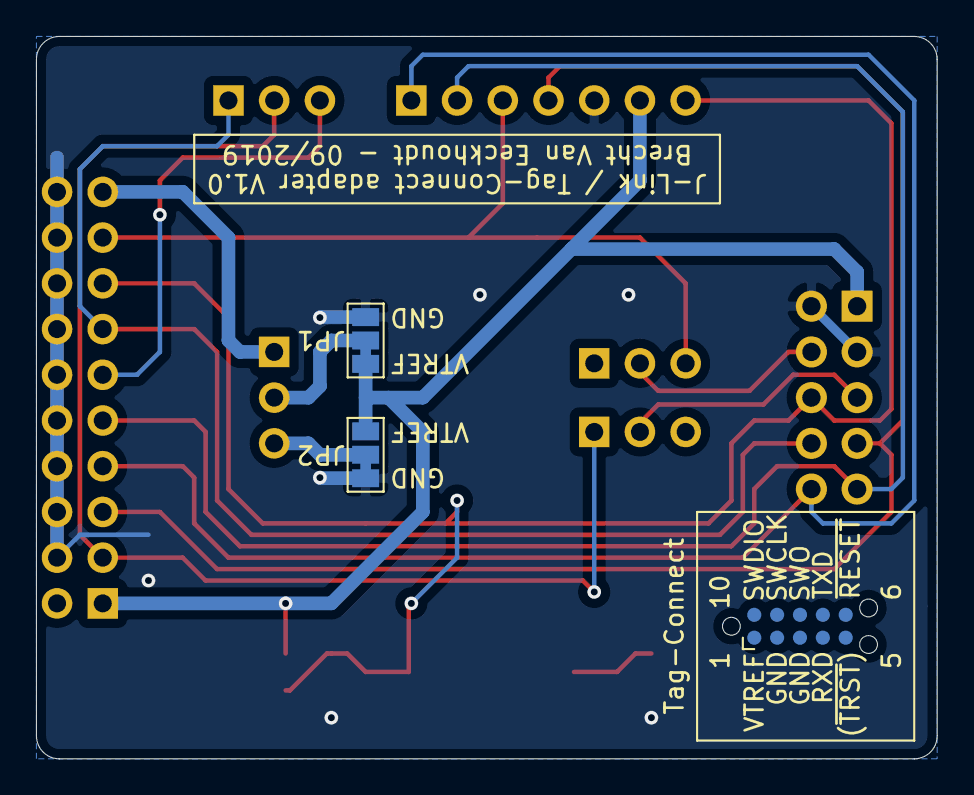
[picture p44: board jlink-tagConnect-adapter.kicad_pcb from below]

Board: 2 copper layers, 50.0 x 40.1 mm, 13 parts (2 on the bottom side), 16 nets.

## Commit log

2019-09-19 Upload initial release
    [jlink-tagConnect-adapter-B_Cu.gbr, jlink-tagConnect-adapter-B_Mask.gbr, jlink-tagConnect-adapter-B_SilkS.gbr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]
2019-09-19 Added note to schematic about RTCK connection
    [jlink-tagConnect-adapter.sch]
2019-11-25 Added v2 schematic
    [jlink-tagConnect-adapter-v2.kicad_pcb, jlink-tagConnect-adapter-v2.sch]
2019-11-26 Changed OSHW logo
    [jlink-tagConnect-adapter-v2.sch]
2019-11-26 Updated with new debug header symbols
    [jlink-tagConnect-adapter-v2.sch]
2019-11-28 Finalized PCB layout
    [jlink-tagConnect-adapter-v2.kicad_pcb]
2019-11-28 Added 3D models
    [FTSH-105-01-L-DV-K.stp, SFH11-xxPC-D10-RA-BK.STEP, SSW-110-02-L-D-RA.stp]
2019-11-28 Updated schematic with new title
    [jlink-tagConnect-adapter-v2.sch]
2019-11-28 Updated 3D models
    [FTSH-105-01-L-DV-K.stl, FTSH-105-01-L-DV-K.stp, SSW-110-02-L-D-RA.stl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]
2019-11-28 Updated PCB with new 3D models
    [jlink-tagConnect-adapter-v2.kicad_pcb]
2019-11-28 Updated BOM
2019-12-03 Updated readme with new BOM
2019-12-10 Added gerber files
    [jlink-tagConnect-adapter-v2-B_Cu.gbl, jlink-tagConnect-adapter-v2-B_Mask.gbs, jlink-tagConnect-adapter-v2-B_Paste.gbp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]
2020-01-14 Update README.md
    Fixed 9 pin FTSH type
2020-12-10 Added V3.0 hardware files
    [FTSH-105-01-L-D-K.stl, SFH11-xxPC-D10-RA-BK.STEP, SSW-110-02-L-D-RA.stl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]
2020-12-10 Added V3.0 PCB pictures
2020-12-11 Added extra link to gerber files
2020-12-26 Added JLCPCB order number position
    [jlink-tagConnect-adapter-v3-B_Cu.gbl, jlink-tagConnect-adapter-v3-B_Mask.gbs, jlink-tagConnect-adapter-v3-B_Paste.gbp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]
2025-03-20 Version 4 upload
    [FTSH-105-01-L-D-K.stl, SFH11-xxPC-D10-RA-BK.STEP, SSW-110-02-L-D-RA.stl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]
2025-03-20 Uploaded v4 gerbers
2025-03-20 Generated v4 gerbers
    [jlink-tagConnect-adapter-v4-B_Cu.gbl, jlink-tagConnect-adapter-v4-B_Mask.gbs, jlink-tagConnect-adapter-v4-B_Paste.gbp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]
2025-03-21 Added serial flashing info ## Updated BOM ## Changed section order
2025-03-27 Updated partnumber in BOM
2025-03-31 Switching back to png ## Tiny documentation changes

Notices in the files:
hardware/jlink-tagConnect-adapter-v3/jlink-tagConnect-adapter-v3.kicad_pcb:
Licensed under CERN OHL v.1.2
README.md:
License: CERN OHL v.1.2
